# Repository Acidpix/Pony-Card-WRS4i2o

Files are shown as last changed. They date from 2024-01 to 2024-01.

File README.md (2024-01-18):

<p align="center" >
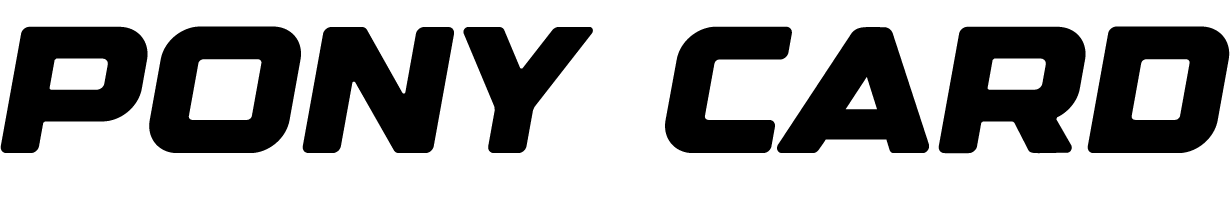
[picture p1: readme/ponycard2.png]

</p>
<p align="center">
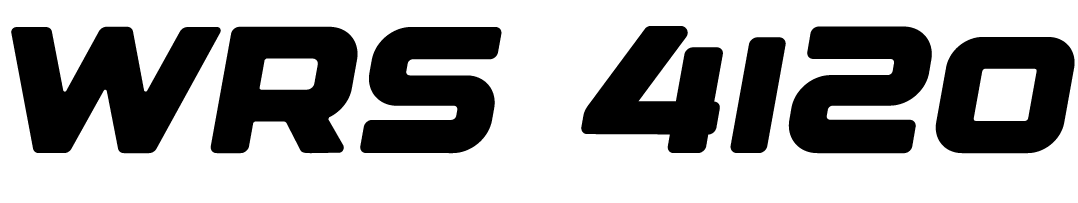
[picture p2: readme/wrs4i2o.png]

</p>

# Pony-Card-WRS4i2o

Pony-Card-WRS4i2o is a Wiegand/RS485 capable card for access controle powered by PoE

# Main feature 
  - Powered by PoE or 12V/2A input
  - Power sercurity device like badge reader in 12V/0.5A
  - Wiegand or RS485 input selectable by switch
  - In Wiegand mode, 1 digital output (e.g for drive 5V Led or buzzer from badge reader)   
  - 4 digital input (3V to 24V)
  - Drive 2 output NO/NC relay (230V/5A Max)
  - Can run on WiFi and/or Ethernet (e.g for failover)
  - Ready to Home assistant with EspHOME (Sample config avaliable)
  - Ready to MQTT with Tasmota (Base firmware avaliable)
  - -20C° +60C° running continous capability
  - Fit in DIN PLC Box like [this](https://fr.aliexpress.com/i/1005004933689728.html)
  - Dimention : 92.4mm X 87.5  

# Esp32 Pin Mapping 
  - GPIO 0 : Flash write mode Conected to CH340
  - GPIO 1 : UART_TX Conected to CH340
  - GPIO 2 : Free use in pin header
  - GPIO 3 : UART_RX Conected to CH340
  - GPIO 4 : Free use in pin header
  - GPIO 5 : Free use in pin header
  - GPIO 6 - 11 : Reserved by flash memory
  - GPIO 12 : Ethernet PHY Power
  - GPIO 13 : Wiegand D0 or RS485 RX
  - GPIO 14 : Wiegand D1 or RS485 TX
  - GPIO 15 : RS485 DIR or digital out in Wiegand mode (e.g for drive status LED on badge reader)
  - GPIO 16 : Free use in pin header
  - GPIO 17 : EMAC Clock out 180
  - GPIO 18 : MDIO(RMII)
  - GPIO 19 : EMAC TXD0(RMII)
  - GPIO 21 : EMAC TX Enable
  - GPIO 22 : EMAC TXD1(RMII)
  - GPIO 23 : MDC(RMII)
  - GPIO 25 : EMAC RXD0(RMII)
  - GPIO 26 : EMAC RXD1(RMII)
  - GPIO 27 : EMAC RX CRS DV
  - GPIO 32 : Relay 1
  - GPIO 33 : Relay 2
  - GPIO 34 : Digital Input 1 (3V - 24V)
  - GPIO 35 : Digital Input 2 (3V - 24V)
  - GPIO 36 : Digital Input 3 (3V - 24V)
  - GPIO 39 : Digital Input 4 (3V - 24V)

# Wiegand ESPHome example 

``` 
esphome:
  name: Pony Card WRS4i2o
  friendly_name: Pony_Card_WRS4i2o

esp32:
  board: esp32dev
  framework:
    type: arduino

# Enable logging
logger:

# Enable Home Assistant API
api:
  encryption:
    key: 

ota:
  password: 

ethernet:
  type: LAN8720
  mdc_pin: GPIO23
  mdio_pin: GPIO18
  clk_mode: GPIO17_OUT
  power_pin: GPIO12

globals:
  - id: autorized_badge
    type: int64_t
    restore_value: no
    initial_value: '5562314525698'

wiegand:
  - id: badgereader
    d0: GPIO13
    d1: GPIO14
    on_raw: 
      - if:
          condition:
            labda : 'return value == id(autorized_badge);
          then:
            - switch.toggle: r1
          else:
            - switch.toggle: r2
            - delay : 1s
            - switch.toggle: r2

binary_sensor:
  - platform: gpio
    pin: 
      number: 34
      inverted: true
    name: "input1"
  - platform: gpio
    pin: 
      number: 35
      inverted: true
    name: "input2"
  - platform: gpio
    pin: 
      number: 36
      inverted: true
    name: "input3"
  - platform: gpio
    pin: 
      number: 39
      inverted: true
    name: "input4"

output:
  - platform: gpio
    pin: 32
    id: 'Relay_1'  
  - platform: gpio
    pin: 33
    id: 'Relay_2'    

switch:
  - platform: output
    name: "Relay 1"
    id: "r1"
    output: 'Relay_1'
  - platform: output
    name: "Relay 2"
    id: "r2"
    output: 'Relay_2'
  - platform: gpio
    name: "LED"
    id: "led"
    pin:
      number: 15
      inverted: true 
``` 

# Misc
R49 was unpopulated resistance, because it's just for very old PoE device, support only type 1 PoE and this type need permanante 10mA current drain. But this produce 0.5w of heat and in certain condition make overhead the board, please populate only if your PoE injector dont work without an be careful of probaly over heating in +50C° environement.

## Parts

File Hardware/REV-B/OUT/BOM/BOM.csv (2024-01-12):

Item | Qty | Reference(s) | Value | LCSC/JLC Part Number | Mouser Part Number
1 | 3 | C1, C2, C7 | 22uF/6.3V/20%/X5R/C0603 | C2991805 | 81-GRM188R60J226ME0D
2 | 1 | C3 | 1nF/2000V/10%/X7R/C1206 | C725573 | 710-885342208024
3 | 9 | C4, C6, C9, C10, C11, C12, C13, C25, C27 | 100nF/16V/10%/X7R/C0402 | C1525 | 81-GRM155R71C104KA8J
4 | 1 | C5 | 56pF 25V | C107007
5 | 1 | C14 | 47uF 16V 1210 | C2918513
6 | 3 | C15, C34, C37 | 100nF/100V/10%/X7R/C0805 | C28233 | 810-C2012X7R2A104K
7 | 1 | C18 | 22uF 25V | C602037
8 | 1 | C26 | 2.2uF/6.3V/10%/X5R/C0603 | C412627 | 81-GCM188R70J225KE2D
9 | 1 | C31 | 1uF/10V/10%/X5R/C0603 | C3000819 | 77-VJ0603Y105KXQCWBC
10 | 1 | C35 | 15uF/100V/20% | C442918 | 661-EKYB101E150MF11D
11 | 1 | C38 | 12pF/50V/5%/COG/C0402 | C386126 | 963-UMK105CG120JVHF
12 | 1 | C39 | 470uF/16V/20%/Low_ESR/RM3.5/8.0x15mm | C428866 | NA
13 | 10 | D1, D3, D5, D7, D8, D9, D10, D11, D12, D16 | B5819W | C64885
14 | 1 | D2 | SMAJ58A/SMA | C151246 | 576-SMAJ58A
15 | 1 | D4 | SS510/100V/5A/0.85V/DO214AB(SMC) | C2985020 | 750-SS510C-HF
16 | 1 | D6 | STS232120B301 | C2985651 | 947-SM712.TCT
17 | 1 | D13 | SS34 | C408258
18 | 2 | D14, D15 | MB10S | C2892569
19 | 1 | FET1 | WPM2015-3/TR | C6562215 | 637-MMFTP3401
20 | 2 | IC2, IC3 | VOD207T | C146234 | 78-VOD207T
21 | 1 | IC4 | THVD1420DR | C3235215 | 595-THVD1420DR
22 | 1 | J2 | 1984963 | C7467028 | 651-1984963
23 | 1 | J3 | 0826-1X1T-GH-F |  | 530-0826-1X1T-GH-F
24 | 1 | J4 | USB_C_Receptacle_USB2.0 | C709357 | USB4105-GF-A
25 | 1 | J5 | 1985069 | C7470124 | 651-1985069
26 | 1 | J6 | 1985001 | C7467032 | 651-1985001
28 | 2 | K1, K2 | G5Q-1-DC12 | C59752 | 653-G5Q-1-DC12
29 | 1 | L1 | Sunlord MWSA1004S-330MT | C408490 | 994-DO3316P-333MLD
30 | 1 | L2 | FB0805/600R/2A | C81034 | 810-MPZ2012S601ATD25
31 | 1 | L3 | 10uH 3.5A 55mR | C168076
32 | 2 | LED1, LED2 | LED/BLUE/0603 | C2962098 | 710-150060VS75000
37 | 1 | PS1 | TPS54202DDCR | C191884 | 595-TPS54202DDCR
38 | 5 | Q1, Q2, Q3, Q4, Q5 | BC817-40(SOT23) | C146798 | 637-BC817-40
39 | 11 | R1, R5, R7, R21, R26, R27, R33, R34, R35, R36, R37 | 1k/R0603 | C73797 | 652-CR0603AFX1001ELF
40 | 4 | R2, R6, R14, R16 | 1.2kR/5%/1W/2512/CR2512-JW-122ELF | C2974106 | 652-CR2512-JW-122ELF
41 | 2 | R3, R17 | 2.2k/R0402 | C4202009 | 71-CRCW04022K20JNEDC
42 | 6 | R4, R19, R22, R23, R24, R30 | 10k/R0402 | C3020235 | 71-RCS040210K0FKED
43 | 4 | R8, R9, R10, R12 | 49.9R/1%/R0402 | C854345 | 667-ERJ-2RKF49R9X
44 | 2 | R11, R38 | 5.1k/R0402 | C105872
45 | 3 | R13, R15, R25 | 220R/R0402 | C284422 | 652-CR0402JW-221GLF
46 | 2 | R18, R32 | 470R/R0603 | C844564 | 71-CRCW0603470RFKEAC
47 | 1 | R20 | 12.1k/1%/R0603 | C2930059 | 652-CR0603FX-1212ELF
48 | 2 | R28, R31 | 10R/5%/pulse resistor/0603 | C319920 | 279-CPF0603F10RC1
49 | 1 | R29 | 130k/R0402 | C102797 | 652-CR0402FX-1303GLF
50 | 1 | R39 | 22.1kR 0402 | C163478
51 | 1 | R42 | 100kR 0402 | C60491
52 | 1 | R43 | 24.9k/1%/R0402 | C852664 | 652-CR0402FX-2492GLF
53 | 1 | R47 | 180k/1%/R0402 | C364850 | 652-CR0402FX-1803GLF
54 | 1 | R48 | 4.42k/1%/1/16W/R0402 | C103045 | 652-CR0402-FX4421GLF
55 | 1 | R49 | 4.7k/R2512 | C269368 | 652-CR2512-JW-472ELF
56 | 1 | R53 | 0.03R/1%/R1206 | C875624 | 71-WSL1206R0300FEA
57 | 1 | R55 | 4.7R/R0402 | C514781 | 652-CR0402-J/-4R7GLF
58 | 1 | R59 | 21k/1%/R0402 | C2692912 | 652-CR0402-FX2102GLF
59 | 1 | R60 | 300k/1%/R0402 | C364989 | 652-CR0402-JW-304GLF
60 | 1 | Reset1 | T1107A(6x3,8x2,5MM) | C97440
61 | 2 | RN1, RN2 | 2.2k/5%/0603x4 | C102658 | 652-CAT16A-222J4LF
62 | 1 | T1 | LMUN2211LT1G(SOT-23) | C12775
63 | 1 | TVS2 | ESDS314DBVR(SOT-23-6) | C1847859 | 595-ESDS314DBVR
64 | 1 | U1 | LAN8710A-EZC(QFN32) | C46185 | 886-LAN8710A-EZC-TR
65 | 1 | U2 | CH340C | C84681
66 | 1 | U3 | ESP-WROOM-32 | C701341 | 356-ESP32WRM32E132PH
67 | 1 | U6 | TPS2376DDAR-H (SO-8) | C544899 | 595-TPS2376D
68 | 1 | U7 | TX4138(ESOIC-8) | C329267

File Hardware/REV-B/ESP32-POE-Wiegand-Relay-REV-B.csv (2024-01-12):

Source: | C:\Users\Pixi\OneDrive\Documents\CAO\Pony-Card-WRS4i2o\Hardware\REV-B\ESP32-POE-Wiegand-Relay-REV-B.kicad_sch
Date: | 1/12/2024 1:11:56 PM
Tool: | Eeschema 7.0.8
Generator: | C:\Program Files\KiCad\7.0\bin\scripting\plugins/bom_csv_grouped_by_value.py
Component Count: | 125
Collated Components:
Item | Qty | Reference(s) | Value | LibPart | Footprint | Datasheet | DNP | Height | LCSC/JLC Part Number | Manufacturer_Name | Manufacturer_Part_Number | Mouser Part Number | Mouser Price/Stock
1 | 3 | C1, C2, C7 | 22uF/6.3V/20%/X5R/C0603 | Device:C | Capacitor_SMD:C_0603_1608Metric | ~ |  |  | C2991805 |  |  | 81-GRM188R60J226ME0D
2 | 1 | C3 | 1nF/2000V/10%/X7R/C1206 | Device:C | Capacitor_SMD:C_1206_3216Metric | ~ |  |  | C725573 |  |  | 710-885342208024
3 | 9 | C4, C6, C9, C10, C11, C12, C13, C25, C27 | 100nF/16V/10%/X7R/C0402 | Device:C | Capacitor_SMD:C_0402_1005Metric | ~ |  |  | C1525 |  |  | 81-GRM155R71C104KA8J
4 | 1 | C5 | 56pF 25V | Device:C_Small | Capacitor_SMD:C_0402_1005Metric | ~ |  |  | C107007
5 | 1 | C14 | 47uF 16V 1210 | Device:C_Small | Capacitor_SMD:C_1210_3225Metric | ~ |  |  | C2918513
6 | 3 | C15, C34, C37 | 100nF/100V/10%/X7R/C0805 | Device:C | Capacitor_SMD:C_0805_2012Metric | ~ |  |  | C28233 |  |  | 810-C2012X7R2A104K
7 | 1 | C18 | 22uF 25V | Device:C_Small | Capacitor_SMD:C_0805_2012Metric | ~ |  |  | C602037
8 | 1 | C26 | 2.2uF/6.3V/10%/X5R/C0603 | Device:C | Capacitor_SMD:C_0603_1608Metric | ~ |  |  | C412627 |  |  | 81-GCM188R70J225KE2D
9 | 1 | C31 | 1uF/10V/10%/X5R/C0603 | Device:C | Capacitor_SMD:C_0603_1608Metric | ~ |  |  | C3000819 |  |  | 77-VJ0603Y105KXQCWBC
10 | 1 | C35 | 15uF/100V/20% | Device:C_Polarized | Capacitor_THT:CP_Radial_D5.0mm_P2.00mm | ~ |  |  | C442918 |  |  | 661-EKYB101E150MF11D
11 | 1 | C38 | 12pF/50V/5%/COG/C0402 | Device:C | Capacitor_SMD:C_0402_1005Metric | ~ |  |  | C386126 |  |  | 963-UMK105CG120JVHF
12 | 1 | C39 | 470uF/16V/20%/Low_ESR/RM3.5/8.0x15mm | Device:C_Polarized | Capacitor_THT:CP_Radial_D8.0mm_P3.50mm | ~ |  |  | C428866 |  |  | NA
13 | 10 | D1, D3, D5, D7, D8, D9, D10, D11, D12, D16 | B5819W | Diode:1N5817 | Diode_SMD:D_SOD-123 | https://www.vishay.com/docs/85748/1n4148w.pdf |  |  | C64885
14 | 1 | D2 | SMAJ58A/SMA | Diode:SMAJ58A | Diode_SMD:D_SMA | https://www.littelfuse.com/media?itemid=75e32973-b177-4ee3-a0ff-cedaf1abdb93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 |  |  | C151246 |  |  | 576-SMAJ58A
15 | 1 | D4 | SS510/100V/5A/0.85V/DO214AB(SMC) | Device:D_Schottky_Small | Diode_SMD:D_SMC | ~ |  |  | C2985020 |  |  | 750-SS510C-HF
16 | 1 | D6 | STS232120B301 | Power_Protection:SP0502BAHT | Package_TO_SOT_SMD:SOT-23 | https://www.mouser.fr/datasheet/2/87/eaton_sts232xxxbxxx_tvs_diode_array_esd_suppressor-1903475.pdf |  |  | C2985651 |  |  | 947-SM712.TCT
17 | 1 | D13 | SS34 | Diode:1N5817 | Diode_SMD:D_SMA | https://www.vishay.com/docs/85748/1n4148w.pdf |  |  | C408258
18 | 2 | D14, D15 | MB10S | SamacSys_Parts:MDB10S YONG | SamacSys_Parts:SOP-4_3.8x4.1mm_P2.54mm_MB10S-YONG | https://datasheet.lcsc.com/lcsc/2109292030_YONGYUTAI-MB10S_C2892569.pdf |  |  | C2892569
19 | 1 | FET1 | WPM2015-3/TR | SamacSys_Parts:P-MOS+DIOD | Package_TO_SOT_SMD:SOT-23-3 |  |  |  | C6562215 |  |  | 637-MMFTP3401
20 | 2 | IC2, IC3 | VOD207T | SamacSys_Parts:VOD207T | SamacSys_Parts:SOIC127P610X323-8N | http://www.vishay.com/docs/81956/vod205t.pdf |  | 3.23 | C146234 | Vishay | VOD207T | 78-VOD207T | https://www.mouser.co.uk/ProductDetail/Vishay-Semiconductors/VOD207T?qs=fbkhFuCHoTaX1ClwC%252BJsLA%3D%3D
21 | 1 | IC4 | THVD1420DR | SamacSys_Parts:THVD1420DR | SamacSys_Parts:SOIC127P600X175-8N | https://www.ti.com/lit/ds/symlink/thvd1420.pdf?ts=1627460855173 |  | 1.75 | C3235215 | Texas Instruments | THVD1420DR | 595-THVD1420DR | https://www.mouser.co.uk/ProductDetail/Texas-Instruments/THVD1420DR?qs=iLbezkQI%252Bsio9fbTvISdEg%3D%3D
22 | 1 | J2 | 1984963 | SamacSys_Parts:1984963 | SamacSys_Parts:1984963 | https://media.digikey.com/pdf/Data%20Sheets/Phoenix%20Contact%20PDFs/COMBICON%20Spring-Cage%20PCB%20Term.%20Blocks.pdf |  | 13.1 | C7467028 | Phoenix Contact | 1984963 | 651-1984963 | https://www.mouser.co.uk/ProductDetail/Phoenix-Contact/1984963?qs=W3wJikR1%252BS77jmVAo79BfA%3D%3D
23 | 1 | J3 | 0826-1X1T-GH-F | SamacSys_Parts:0826-1X1T-GH-F | SamacSys_Parts:08261X1TGHF | https://datasheet.datasheetarchive.com/originals/distributors/Datasheets-DGA2/203609.pdf |  |  |  | Bel Magnetic Solutions | 0826-1X1T-GH-F | 530-0826-1X1T-GH-F | https://www.mouser.co.uk/ProductDetail/Bel-Magnetic-Solutions/0826-1X1T-GH-F?qs=SRYZG9HaIQ0Mc3bZi1IotQ%3D%3D
24 | 1 | J4 | USB_C_Receptacle_USB2.0 | Connector:USB_C_Receptacle_USB2.0 | Connector_USB:USB_C_Receptacle_G-Switch_GT-USB-7010ASV | https://www.usb.org/sites/default/files/documents/usb_type-c.zip |  |  | C709357 |  |  | USB4105-GF-A
25 | 1 | J5 | 1985069 | SamacSys_Parts:1985069 | SamacSys_Parts:1985069 | https://datasheet.datasheetarchive.com/originals/dk/DKDS-5/85375.pdf |  | 13.1 | C7470124 | Phoenix Contact | 1985069 | 651-1985069 | https://www.mouser.co.uk/ProductDetail/Phoenix-Contact/1985069?qs=gjk32EaArKK7mdP%252BL%2F2B4Q%3D%3D
26 | 1 | J6 | 1985001 | SamacSys_Parts:1985001 | SamacSys_Parts:1985001 | https://datasheet.datasheetarchive.com/originals/distributors/SFDatasheet-2/sf-00059053.pdf |  | 13.1 | C7467032 | Phoenix Contact | 1985001 | 651-1985001 | https://www.mouser.co.uk/ProductDetail/Phoenix-Contact/1985001?qs=zNxsRDw9Fqyp1BhRo7hyKA%3D%3D
27 | 1 | J8 | Conn_01x10 | Connector_Generic:Conn_01x10 | Connector_PinHeader_2.54mm:PinHeader_1x10_P2.54mm_Vertical | ~
28 | 2 | K1, K2 | G5Q-1-DC12 | SamacSys_Parts:G5Q-1-DC12 | SamacSys_Parts:G5Q1DC12 | https://componentsearchengine.com/Datasheets/1/G5Q-1-DC12.pdf |  | 16.2 | C59752 | Omron Electronics | G5Q-1-DC12 | 653-G5Q-1-DC12 | https://www.mouser.co.uk/ProductDetail/Omron-Electronics/G5Q-1-DC12?qs=nNiD76Ca0%252Bu28Ix61rgPyA%3D%3D
29 | 1 | L1 | Sunlord MWSA1004S-330MT | SamacSys_Parts:DO3316P-333MLD | Inductor_SMD:L_Sunlord_MWSA1004S | https://www.coilcraft.com/pdfs/do3316p.pdf |  | 5.21 | C408490 | COILCRAFT | DO3316P-333MLD | 994-DO3316P-333MLD | https://www.mouser.co.uk/ProductDetail/Coilcraft/DO3316P-333MLD?qs=zCSbvcPd3paYSfmHDR4Exw%3D%3D
30 | 1 | L2 | FB0805/600R/2A | Device:L | Resistor_SMD:R_0805_2012Metric | ~ |  |  | C81034 |  |  | 810-MPZ2012S601ATD25
31 | 1 | L3 | 10uH 3.5A 55mR | Device:L | Inductor_SMD:L_Changjiang_FNR6045S | ~ |  |  | C168076
32 | 2 | LED1, LED2 | LED/BLUE/0603 | Device:LED | LED_SMD:LED_0603_1608Metric | ~ |  |  | C2962098 |  |  | 710-150060VS75000
33 | 1 | MH1 | Mounting_hole_Shield_3.3mm | :Mounting_hole_Shield_3.3mm_2 | MountingHole:MountingHole_3.2mm_M3_Pad |  |  |  | NA |  |  | NA
34 | 1 | MH2 | Mounting_hole_Shield_3.3mm | :Mounting_hole_Shield_3.3mm_3 | MountingHole:MountingHole_3.2mm_M3_Pad |  |  |  | NA |  |  | NA
35 | 1 | MH3 | Mounting_hole_Shield_3.3mm | import-Library:Mounting_hole_Shield_3.3mm | MountingHole:MountingHole_3.2mm_M3_Pad |  |  |  | NA |  |  | NA
36 | 1 | MH4 | Mounting_hole_Shield_3.3mm | :Mounting_hole_Shield_3.3mm_1 | MountingHole:MountingHole_3.2mm_M3_Pad |  |  |  | NA |  |  | NA
37 | 1 | PS1 | TPS54202DDCR | SamacSys_Parts:TPS54202DDCR | SOT95P280X110-6N | http://www.ti.com/lit/gpn/tps54202 |  | 1.1 | C191884 | Texas Instruments | TPS54202DDCR | 595-TPS54202DDCR | https://www.mouser.co.uk/ProductDetail/Texas-Instruments/TPS54202DDCR?qs=uP22XH7NdCsJtN%2Fq54jCtQ%3D%3D
38 | 5 | Q1, Q2, Q3, Q4, Q5 | BC817-40(SOT23) | Device:Q_NPN_BEC | Package_TO_SOT_SMD:SOT-23 | ~ |  |  | C146798 |  |  | 637-BC817-40
39 | 11 | R1, R5, R7, R21, R26, R27, R33, R34, R35, R36, R37 | 1k/R0603 | Device:R | Resistor_SMD:R_0603_1608Metric | ~ |  |  | C73797 |  |  | 652-CR0603AFX1001ELF
40 | 4 | R2, R6, R14, R16 | 1.2kR/5%/1W/2512/CR2512-JW-122ELF | Device:R | Resistor_SMD:R_2512_6332Metric | ~ |  |  | C2974106 |  |  | 652-CR2512-JW-122ELF
41 | 2 | R3, R17 | 2.2k/R0402 | Device:R | Resistor_SMD:R_0402_1005Metric | ~ |  |  | C4202009 |  |  | 71-CRCW04022K20JNEDC
42 | 6 | R4, R19, R22, R23, R24, R30 | 10k/R0402 | Device:R | Resistor_SMD:R_0402_1005Metric | ~ |  |  | C3020235 |  |  | 71-RCS040210K0FKED
43 | 4 | R8, R9, R10, R12 | 49.9R/1%/R0402 | Device:R | Resistor_SMD:R_0402_1005Metric | ~ |  |  | C854345 |  |  | 667-ERJ-2RKF49R9X
44 | 2 | R11, R38 | 5.1k/R0402 | Device:R | Resistor_SMD:R_0402_1005Metric | ~ |  |  | C105872
45 | 3 | R13, R15, R25 | 220R/R0402 | Device:R | Resistor_SMD:R_0402_1005Metric | ~ |  |  | C284422 |  |  | 652-CR0402JW-221GLF
46 | 2 | R18, R32 | 470R/R0603 | Device:R | Resistor_SMD:R_0603_1608Metric | ~ |  |  | C844564 |  |  | 71-CRCW0603470RFKEAC
47 | 1 | R20 | 12.1k/1%/R0603 | Device:R | Resistor_SMD:R_0603_1608Metric | ~ |  |  | C2930059 |  |  | 652-CR0603FX-1212ELF
48 | 2 | R28, R31 | 10R/5%/pulse resistor/0603 | Device:R | Resistor_SMD:R_0603_1608Metric | ~ |  |  | C319920 |  |  | 279-CPF0603F10RC1
49 | 1 | R29 | 130k/R0402 | Device:R | Resistor_SMD:R_0402_1005Metric | ~ |  |  | C102797 |  |  | 652-CR0402FX-1303GLF
50 | 1 | R39 | 22.1kR 0402 | Device:R_Small | Resistor_SMD:R_0402_1005Metric | ~ |  |  | C163478
51 | 1 | R42 | 100kR 0402 | Device:R_Small | Resistor_SMD:R_0402_1005Metric | ~ |  |  | C60491
52 | 1 | R43 | 24.9k/1%/R0402 | Device:R | Resistor_SMD:R_0402_1005Metric | ~ |  |  | C852664 |  |  | 652-CR0402FX-2492GLF
53 | 1 | R47 | 180k/1%/R0402 | Device:R | Resistor_SMD:R_0402_1005Metric | ~ |  |  | C364850 |  |  | 652-CR0402FX-1803GLF
54 | 1 | R48 | 4.42k/1%/1/16W/R0402 | Device:R | Resistor_SMD:R_0402_1005Metric | ~ |  |  | C103045 |  |  | 652-CR0402-FX4421GLF
55 | 1 | R49 | 4.7k/R2512 | Device:R | Resistor_SMD:R_2512_6332Metric | ~ |  |  | C269368 |  |  | 652-CR2512-JW-472ELF
56 | 1 | R53 | 0.03R/1%/R1206 | Device:R | Resistor_SMD:R_1206_3216Metric | ~ |  |  | C875624 |  |  | 71-WSL1206R0300FEA
57 | 1 | R55 | 4.7R/R0402 | Device:R | Resistor_SMD:R_0402_1005Metric | ~ |  |  | C514781 |  |  | 652-CR0402-J/-4R7GLF
58 | 1 | R59 | 21k/1%/R0402 | Device:R | Resistor_SMD:R_0402_1005Metric | ~ |  |  | C2692912 |  |  | 652-CR0402-FX2102GLF
59 | 1 | R60 | 300k/1%/R0402 | Device:R | Resistor_SMD:R_0402_1005Metric | ~ |  |  | C364989 |  |  | 652-CR0402-JW-304GLF
60 | 1 | Reset1 | T1107A(6x3,8x2,5MM) | import-Library:SIDE_WTCM-TR(3x4) | Button_Switch_THT:SW_PUSH_6mm |  |  |  | C97440
61 | 2 | RN1, RN2 | 2.2k/5%/0603x4 | SamacSys_Parts:CAY16-222J4LF | Resistor_SMD:R_Array_Concave_4x0603 | http://www.bourns.com/docs/Product-Datasheets/CATCAY.pdf |  |  | C102658 | Bourns | CAY16-222J4LF | 652-CAT16A-222J4LF | https://www.mouser.co.uk/ProductDetail/Bourns/CAY16-222J4LF?qs=36H9kbV3T2y0WLGod7%2FgTA%3D%3D
62 | 1 | T1 | LMUN2211LT1G(SOT-23) | SamacSys_Parts:LMUN2211LT1G(SOT-23) | Package_TO_SOT_SMD:SOT-23 |  |  |  | C12775
63 | 1 | TVS2 | ESDS314DBVR(SOT-23-6) | SamacSys_Parts:ESDS314DBVR(SOT-23-5) | Package_TO_SOT_SMD:SOT-23-6 | https://www.ti.com/lit/gpn/esds314 |  |  | C1847859 |  |  | 595-ESDS314DBVR
64 | 1 | U1 | LAN8710A-EZC(QFN32) | SamacSys_Parts:LAN8710A-EZC(QFN32) | SamacSys_Parts:QFN50P500X500X100-33N-D |  |  |  | C46185 |  |  | 886-LAN8710A-EZC-TR
65 | 1 | U2 | CH340C | Interface_USB:CH340C | Package_SO:SOIC-16_3.9x9.9mm_P1.27mm | https://datasheet.lcsc.com/szlcsc/Jiangsu-Qin-Heng-CH340C_C84681.pdf |  |  | C84681
66 | 1 | U3 | ESP-WROOM-32 | SamacSys_Parts:ESP-WROOM-32 | SamacSys_Parts:ESP32WROOM32EN4 |  |  |  | C701341 |  |  | 356-ESP32WRM32E132PH
67 | 1 | U6 | TPS2376DDAR-H (SO-8) | SamacSys_Parts:TPS2375PW(TSSOP-8) | SamacSys_Parts:SOIC127P600X175-8N | https://www.ti.com/lit/gpn/tps2375 |  |  | C544899 |  |  | 595-TPS2376D
68 | 1 | U7 | TX4138(ESOIC-8) | SamacSys_Parts:TX4138(ESOIC-8) | SamacSys_Parts:SOIC8E | https://datasheet.lcsc.com/lcsc/1811141153_XDS-TX4138_C329267.pdf |  |  | C329267

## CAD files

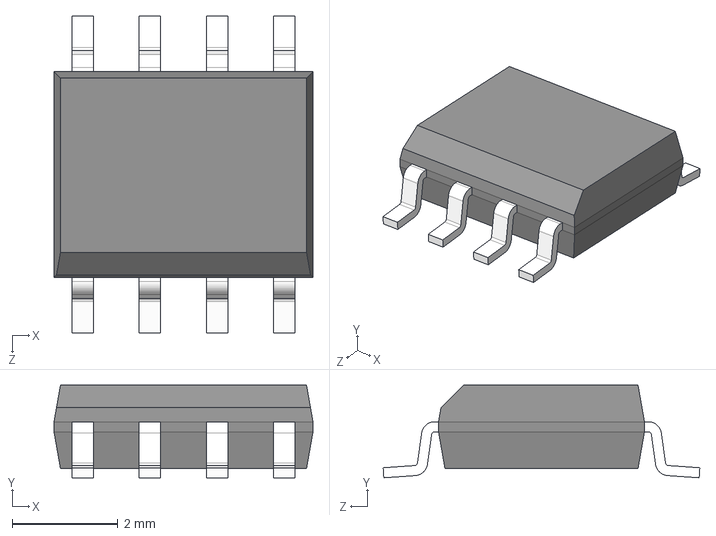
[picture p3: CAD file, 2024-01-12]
Hardware/REV-B/3d/SO-8_150mil---SN65HVDA1050AQDRQ1.STEP
4.90 x 1.75 x 5.99 mm

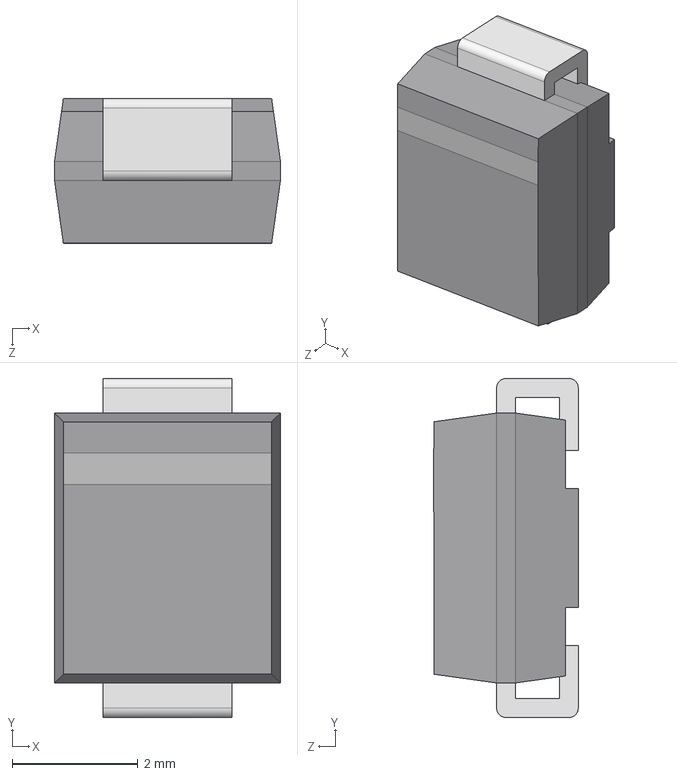
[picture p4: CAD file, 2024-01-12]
Hardware/REV-B/3d/DO-214AA_SMB.step
3.60 x 5.40 x 2.30 mm

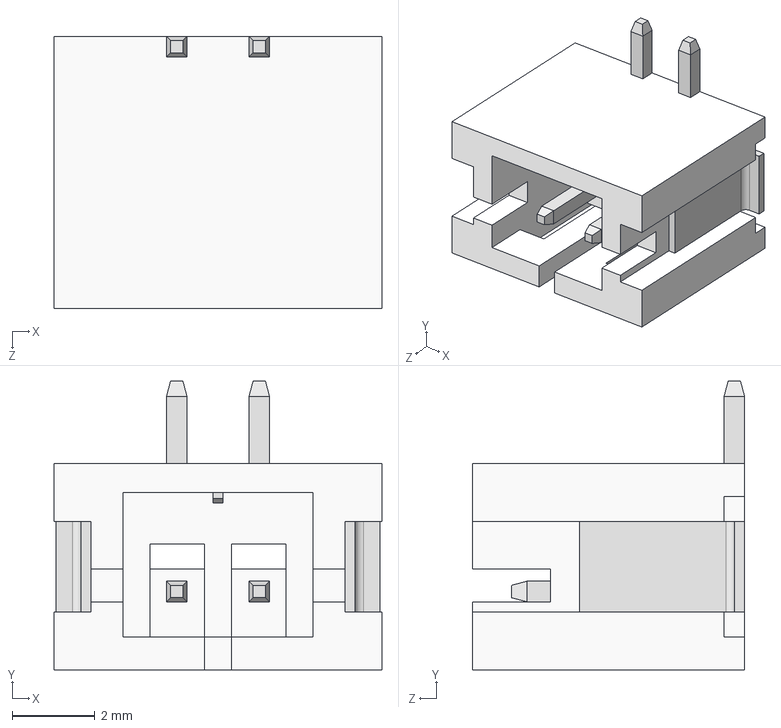
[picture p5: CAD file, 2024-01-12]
Hardware/REV-B/3d/JST_B2B-PH-SM4-TB(DW02R).step
7.95 x 7.00 x 6.60 mm

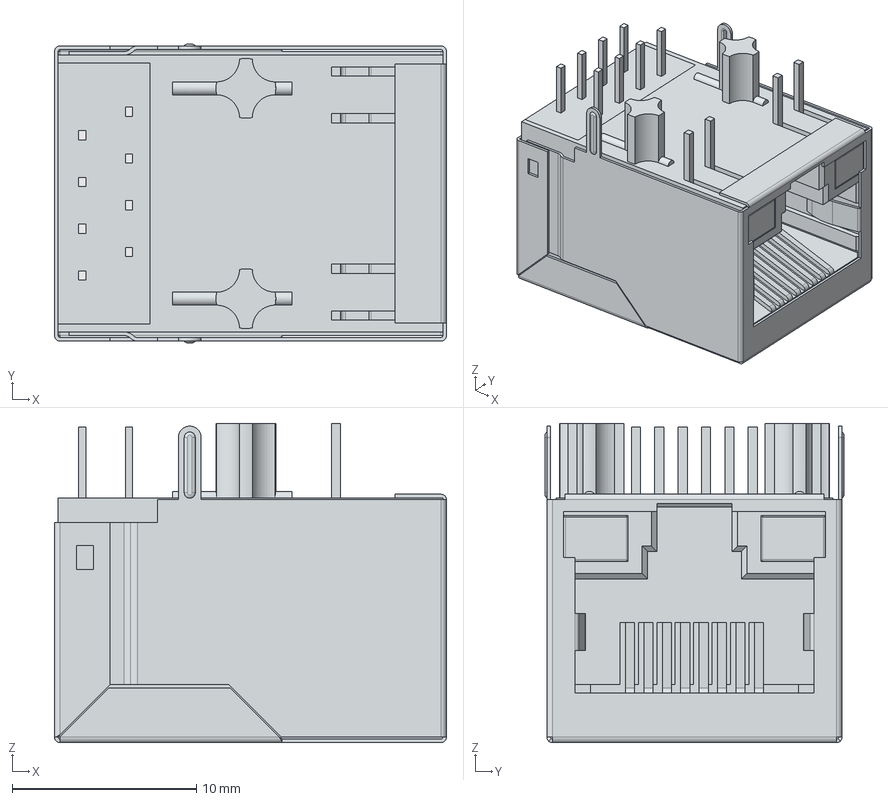
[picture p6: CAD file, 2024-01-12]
Hardware/REV-B/3d/Connector_1Port_RJ45_Magjack_10-100Base-T_AutoMDIX_Wurth_Electronics-7499010441.stp
21.3 x 16.2 x 17.4 mm
Shielding
Insulator 3
Insulator 1
Insulator 2
Green_Yellow_LED x 2

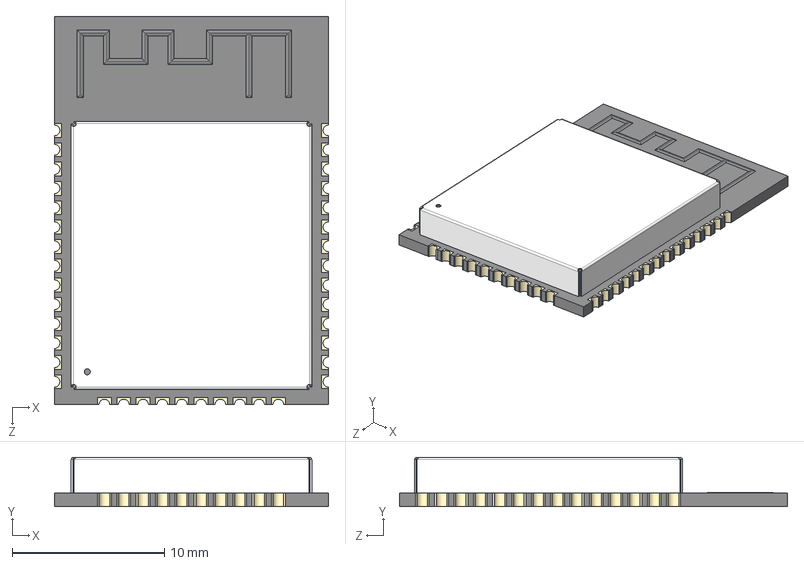
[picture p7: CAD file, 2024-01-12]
Hardware/REV-B/3d/ESP32-WROOM-32D-56544.STEP
18.0 x 3.25 x 25.5 mm

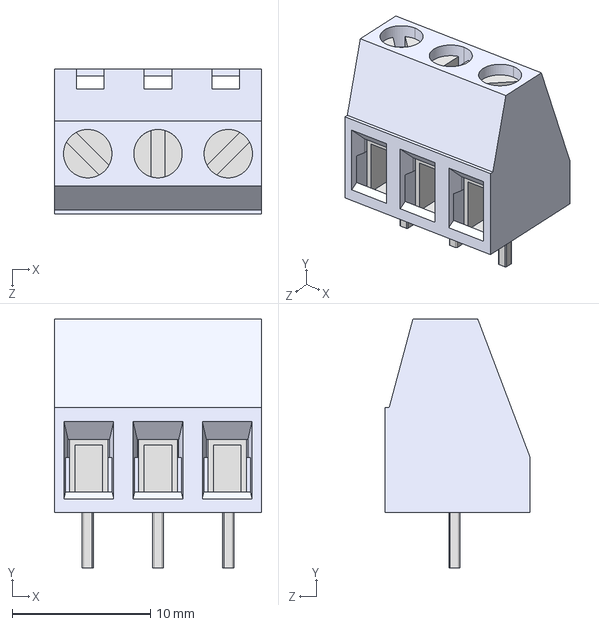
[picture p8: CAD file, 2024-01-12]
Hardware/REV-B/3d/klema-5mm-3pin.step
15.0 x 18.0 x 10.5 mm

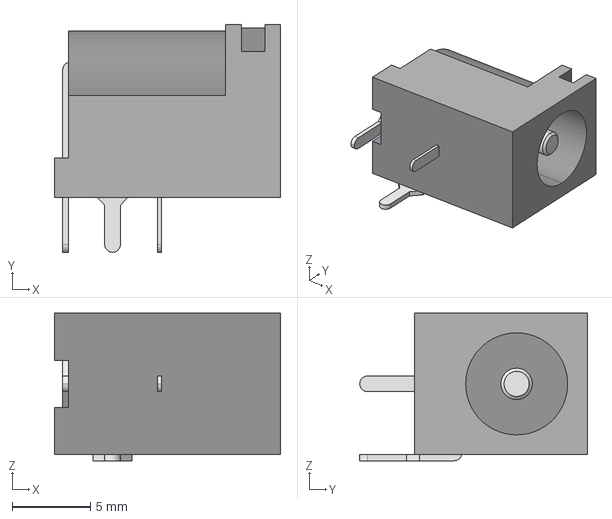
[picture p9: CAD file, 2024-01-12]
Hardware/REV-B/3d/pj-102ah.stp
14.4 x 14.5 x 9.40 mm

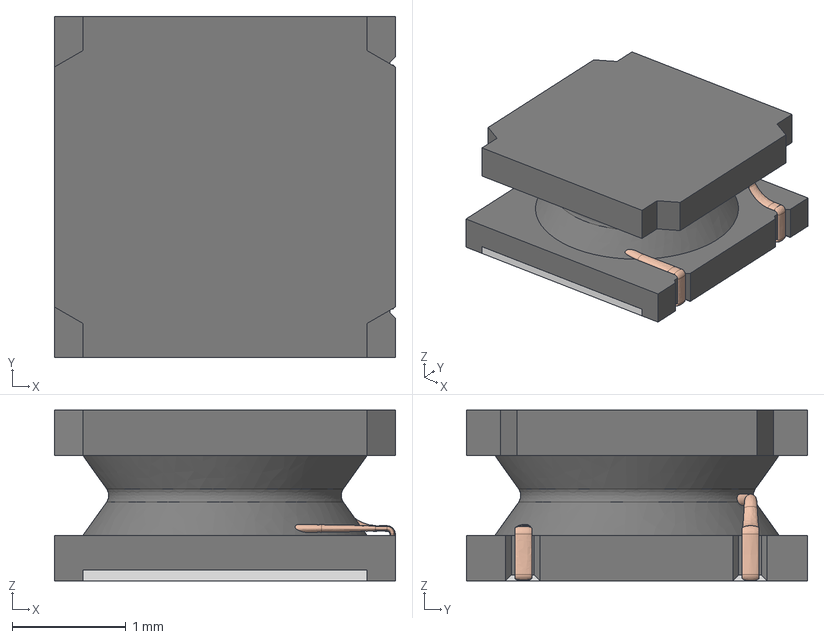
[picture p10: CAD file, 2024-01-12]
Hardware/REV-B/3d/L-CD32_shielded.step
3.00 x 3.00 x 1.50 mm

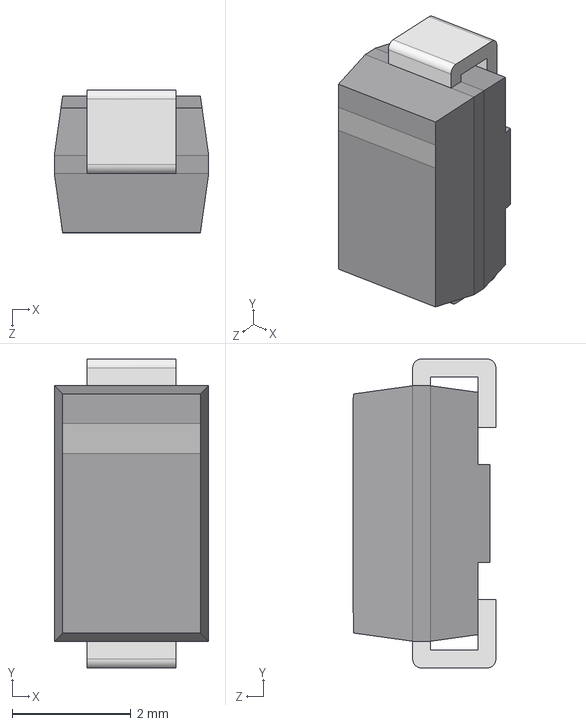
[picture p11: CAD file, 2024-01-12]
Hardware/REV-B/3d/DO-214AC_SMA.step
2.60 x 5.20 x 2.40 mm

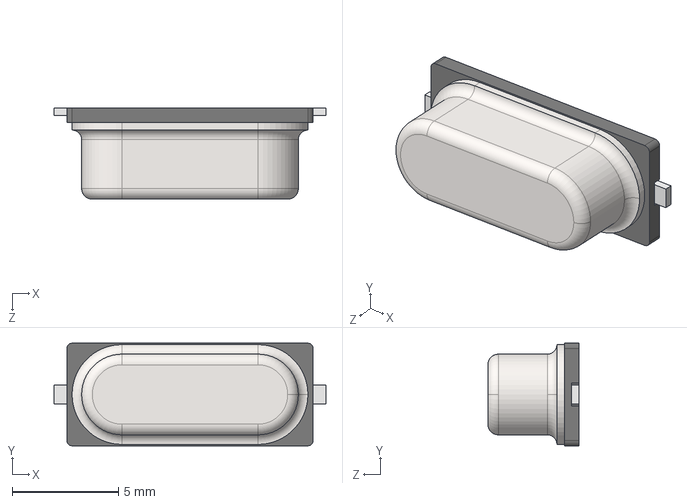
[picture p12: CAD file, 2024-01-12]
Hardware/REV-B/3d/User_Library-Crystal_HC49_US-SM.step
12.8 x 4.83 x 4.30 mm

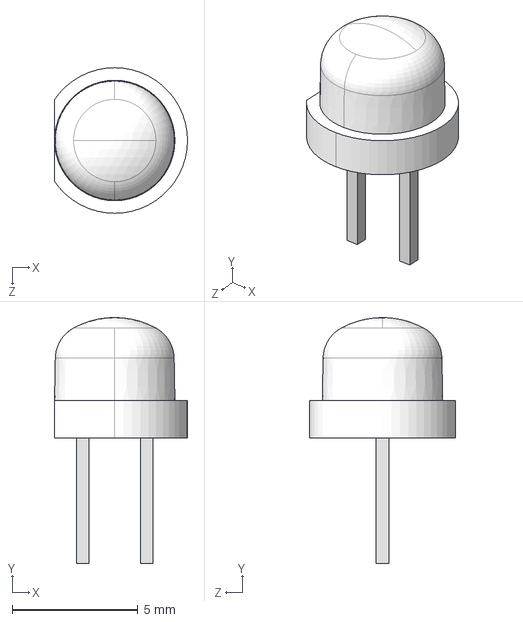
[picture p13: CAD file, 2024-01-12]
Hardware/REV-B/3d/LED5mm_120.STEP
5.30 x 9.80 x 5.80 mm

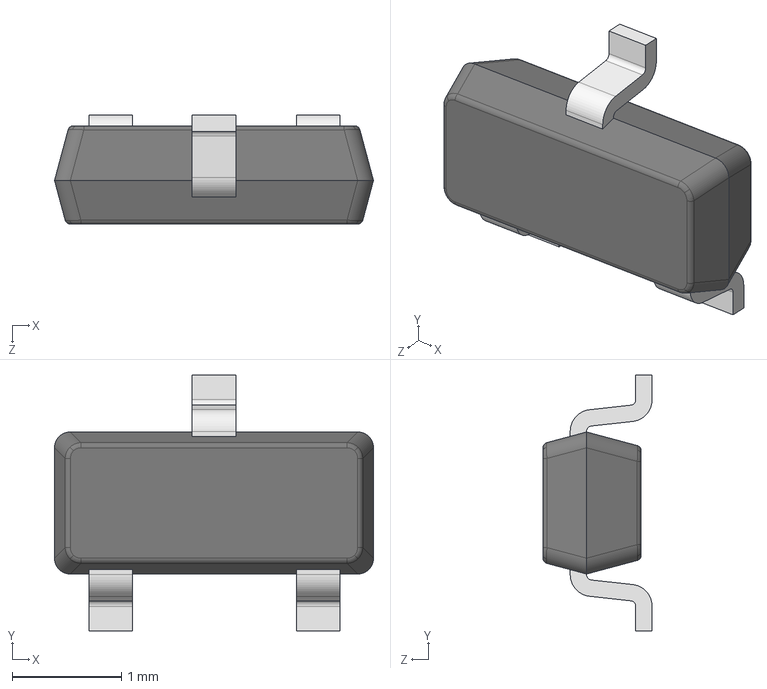
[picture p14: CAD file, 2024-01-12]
Hardware/REV-B/3d/BAT54.step
2.92 x 2.34 x 1.00 mm

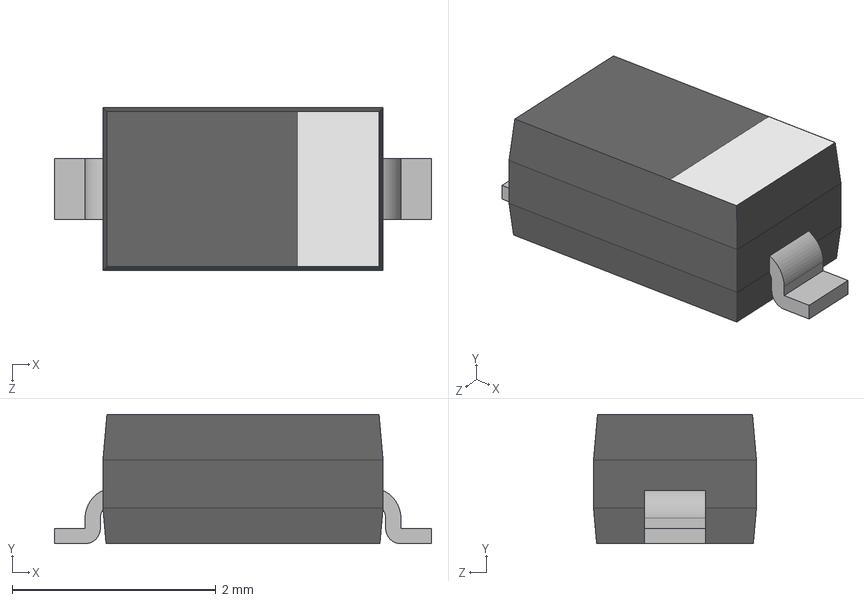
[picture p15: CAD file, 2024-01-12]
Hardware/REV-B/3d/SOD123.step
3.70 x 1.27 x 1.60 mm

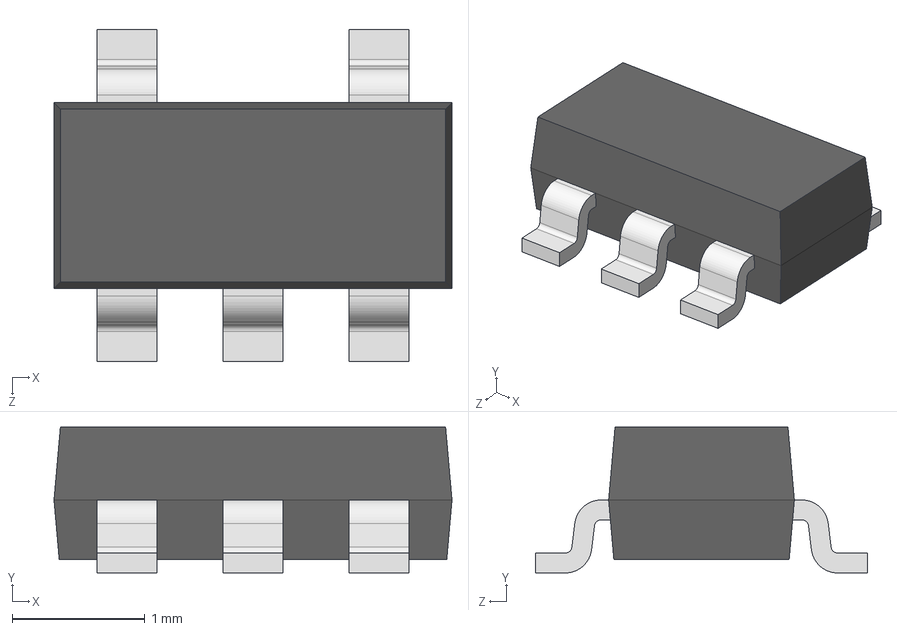
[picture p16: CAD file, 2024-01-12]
Hardware/REV-B/3d/SOT-23-5.step
3.00 x 1.10 x 2.50 mm

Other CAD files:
Hardware/REV-B/3d/QSG5032.step
Hardware/REV-B/3d/TEConnectivity -ORWH-SH-124D1F000.stp
Hardware/REV-B/3d/QFN32_5x5.step
Hardware/REV-B/3d/BH-10__64.step
Hardware/REV-A/3d/434121043836 (rev1).stp
Hardware/REV-A/3d/5040771891.stp
Hardware/REV-A/3d/BH-10__64.step
Hardware/REV-A/3d/QFN32_5x5.step
Hardware/REV-A/3d/QSG5032.step
Hardware/REV-A/3d/SOT-23.step
Hardware/REV-A/3d/TEConnectivity -ORWH-SH-124D1F000.stp
Hardware/REV-A/3d/User Library-GP1UE26.STEP
Hardware/REV-A/3d/esp-wroom-32.step
Hardware/REV-A/3d/usb_micro_4p.stp
Hardware/REV-B/3d/434121043836 (rev1).stp
Hardware/REV-B/3d/5040771891.stp
Hardware/REV-B/3d/SOT-23.step
Hardware/REV-B/3d/User Library-GP1UE26.STEP
Hardware/REV-B/3d/esp-wroom-32.step
Hardware/REV-B/3d/usb_micro_4p.stp

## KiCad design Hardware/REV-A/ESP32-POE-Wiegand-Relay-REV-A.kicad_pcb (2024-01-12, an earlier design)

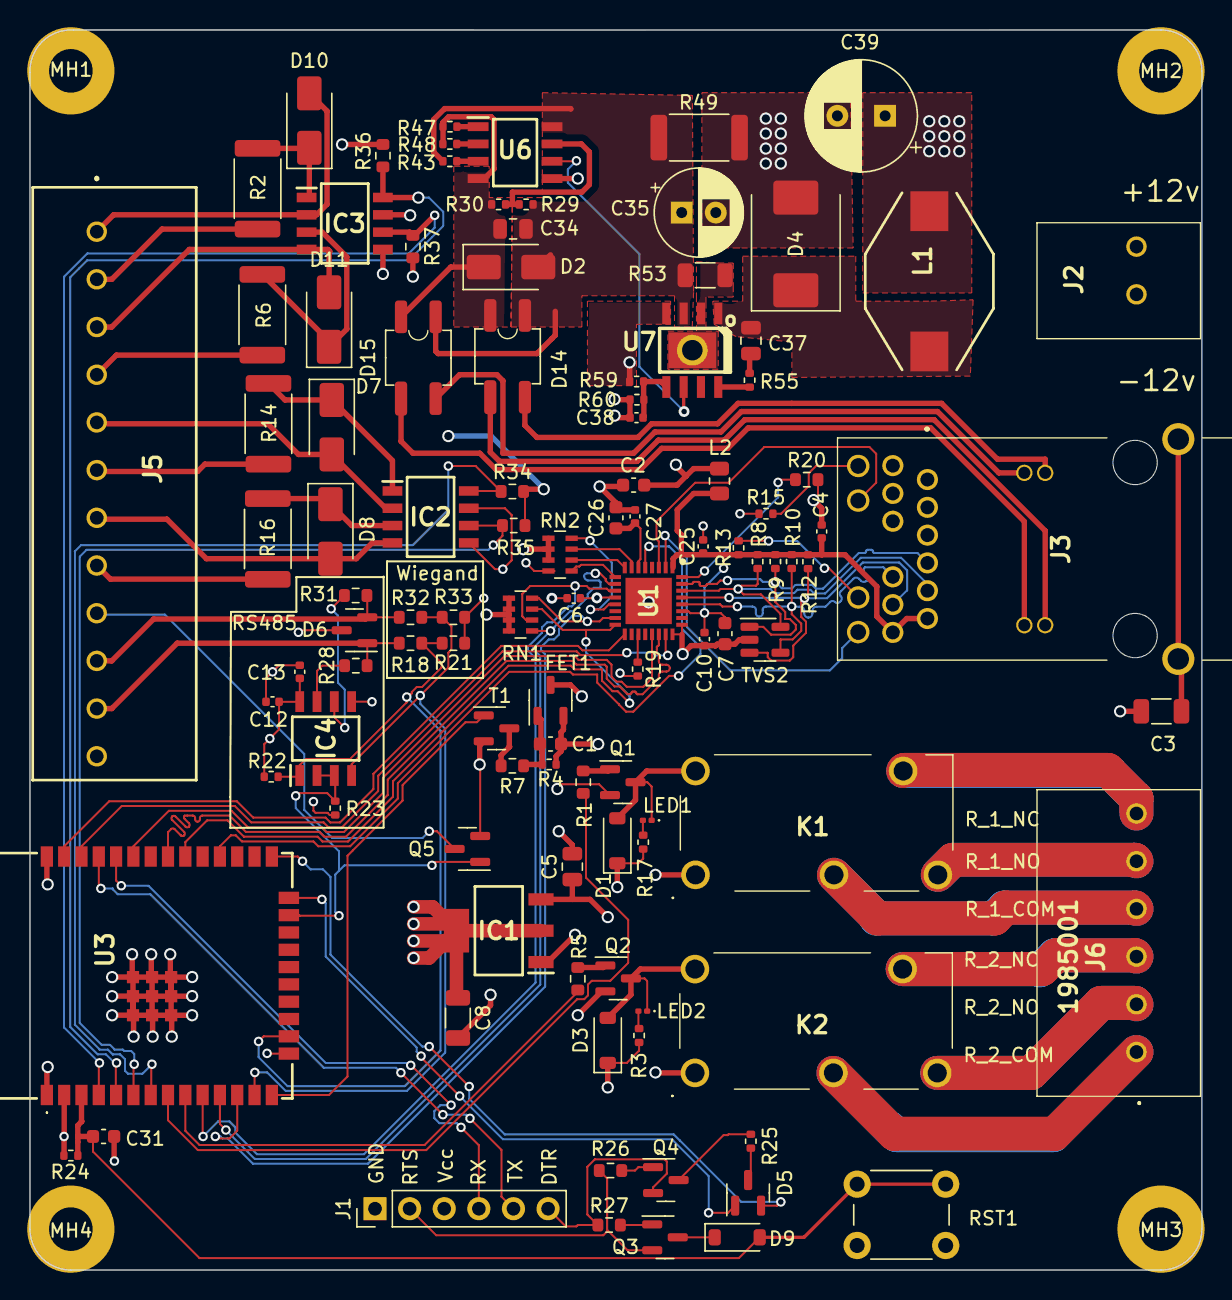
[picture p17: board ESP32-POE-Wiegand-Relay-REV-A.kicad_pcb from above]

Board: 4 copper layers, 86.0 x 91.0 mm, 111 parts (0 on the bottom side), 99 nets.

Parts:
C1, C2, C7: 22uF/6.3V/20%/X5R/C0603; C_0603_1608Metric
C3: 1nF/2000V/10%/X7R/C1206; C_1206_3216Metric
C4, C6, C10, C12, C13, C25, C27: 100nF/16V/10%/X7R/C0402; C_0402_1005Metric
C5: 10uF/16v/10%/0805; C_0805_2012Metric
C8: 22uF/6.3v/10%/1206; C_1206_3216Metric
C26: 2.2uF/6.3V/10%/X5R/C0603; C_0603_1608Metric
C31: 1uF/10V/10%/X5R/C0603; C_0603_1608Metric
C34, C37: 100nF/100V/10%/X7R/C0805; C_0805_2012Metric
C35: 15uF/100V/20%/RM2.5/6.3x11mm(Farnell:1281844); CP_Radial_D6.3mm_P2.50mm
C38: 12pF/50V/5%/COG/C0402; C_0402_1005Metric
C39: 470uF/16V/20%/Low_ESR/RM3.5/8.0x15mm; CP_Radial_D8.0mm_P3.50mm
D1, D3, D9: 1N5819S4(SOD-123); D_SOD-123
D2: SMAJ58A/SMA; D_SMA
D4: SS510/100V/5A/0.85V/DO214AB(SMC); D_SMC
D5: BAT54C(SOT23-3); SOT-23
D6: STS232120B301; SOT-23
D7, D8, D10, D11: Diode 1KV; D_SMA
D14, D15: MDB10S YONG; SOP-4_3.8x4.1mm_P2.54mm_MB10S-YONG
FET1: WPM2015-3/TR; SOT-23-3
IC1: AZ1117CH-3.3TRG1; SOT230P700X180-4N
IC2, IC3: VOD207T; SOIC127P610X323-8N
IC4: THVD1420DR; SOIC127P600X175-8N
J1: Conn_01x06_MountingPin; PinHeader_1x06_P2.54mm_Vertical
J2: 1984963
J3: 0826-1X1T-GH-F; 08261X1TGHF
J5: 1985069
J6: 1985001
K1, K2: G5Q-1-DC12; G5Q1DC12
L1: DO3316P-333MLD; DO3316P333MLD
L2: FB0805/600R/2A; R_0805_2012Metric
LED1, LED2: LED/GREEN/0603; LED_0201_0603Metric
MH1, MH2, MH3, MH4: Mounting_hole_Shield_3.3mm; MountingHole_3.2mm_M3_Pad
Q1, Q2, Q3, Q4, Q5: BC817-40(SOT23); SOT-23
R1, R5, R7, R21, R26, R27, R33, R34, R35, R36, R37: 1k/R0603; R_0603_1608Metric
R2, R6, R14, R16: 1.2kR/5%/1W/2512/CR2512-JW-122ELF; R_2512_6332Metric
R3, R13, R15, R17: 2.2k/R0402; R_0402_1005Metric
R4, R19, R22, R23, R24, R30: 10k/R0402; R_0402_1005Metric
R8, R9, R10, R12: 49.9R/1%/R0402; R_0402_1005Metric
R18, R32: 470R/R0603; R_0603_1608Metric
R20: 12.1k/1%/R0603; R_0603_1608Metric
R25: 220R/R0402; R_0402_1005Metric
R28, R31: 10R/5%/pulse resistor/0603; R_0603_1608Metric
R29: 130k/R0402; R_0402_1005Metric
R43: 24.9k/1%/R0402; R_0402_1005Metric
R47: 180k/1%/R0402; R_0402_1005Metric
R48: 4.42k/1%/1/16W/R0402; R_0402_1005Metric
R49: 4.7k/R2512; R_2512_6332Metric
R53: 0.03R/1%/R1206; R_1206_3216Metric
R55: 4.7R/R0402; R_0402_1005Metric
R59: 21k/1%/R0402; R_0402_1005Metric
R60: 300k/1%/R0402; R_0402_1005Metric
RN1, RN2: 2.2k/5%/0603x4; R_Array_Concave_4x0603
RST1: T1107A(6x3,8x2,5MM); SW_PUSH_6mm
T1: LMUN2211LT1G(SOT-23); SOT-23
TVS2: ESDS314DBVR(SOT-23-5); SOT-23-5
U1: LAN8710A-EZC(QFN32); QFN50P500X500X100-33N-D
U3: ESP-WROOM-32; ESP32WROOM32EN4
U6: TPS2376DDAR-H (SO-8); SOIC127P600X175-8N
U7: TX4138(ESOIC-8); SOIC8E

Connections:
+3.3V: C1.1, C8.1, C12.2, C13.2, FET1.2, IC1.2 (OUTPUT), IC1.4 (VOUT), IC4.8 (VCC), J1.3, R4.1, R22.1, R24.1, R34.2, R35.2, R36.2, R37.2, U3.2 (3V3)
+3V3: C2.1, C6.1, FET1.3, L2.1, R19.2, RN1.5 (R4_2), RN1.6 (R3_2), RN1.7 (R2_2), RN1.8 (R1_2), RN2.8 (R1_2), U1.12 (VDDIO)
+12V: C5.1, C38.1, C39.1, D1.1 (K), D3.1 (K), IC1.3 (INPUT), J2.1, K1.1 (COIL_1), K2.1 (COIL_1), L1.2, R3.2, R17.2, R60.1
/+Input1: J5.8, R16.1
/+Input2: J5.6, R14.1
/+Input3: J5.4, R6.1
/+Input4: J5.2, R2.1
/-Input1: D8.2 (A), IC2.4 (C_2), J5.7
/-Input2: D7.2 (A), IC2.2 (C_1), J5.5
/-Input3: D11.2 (A), IC3.4 (C_2), J5.3
/-Input4: D10.2 (A), IC3.2 (C_1), J5.1
/D_Com: D5.3, R25.1
/ESP_EN: C31.2, D9.2 (A), R24.2, RST1.1, U3.3 (EN)
/GPI34/Input1: IC2.6 (C_3), R35.1, U3.6 (GPI34/ADC1_CH6/RTC_GPIO4)
/GPI35/Input2: IC2.8 (C_4), R34.1, U3.7 (GPI35/ADC1_CH7/RTC_GPIO5)
/GPI36/Input3: IC3.6 (C_3), R37.1, U3.4 (GPI36/SENSOR_VP/ADC_H/ADC1_CH0/RTC_GPIO0)
/GPI39/Input4: IC3.8 (C_4), R36.1, U3.5 (GPI39/SENSOR_VN/ADC1_CH3/ADC_H/RTC_GPIO3)
/GPIO0: D5.2, U3.25 (GPIO0/ADC2_CH1/TOUCH1/RTC_GPIO11/CLK_OU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)
/GPIO1/UART_TX0: J1.5, U3.35 (GPIO1/U0TXD/CLK_OUT3/EMAC_RXD2)
/GPIO2: D5.1, U3.24 (GPIO2/ADC2_CH2/TOUCH2/RTC_GPIO12/HSPIWP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)
/GPIO3/UART_RX0: J1.4, U3.34 (GPIO3/U0RXD/CLK_OUT2)
/GPIO12/PHY_PWR: T1.1 (B), U3.14 (GPIO12/ADC2_CH5/TOUCH5/RTC_GPIO15/MTDI/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)
/GPIO13/Wiegand_D0/RS485_RX: IC4.1 (R), R18.2, R21.2, R22.2, U3.16 (GPIO13/ADC2_CH4/TOUCH4/RTC_GPIO14/MTCK/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)
/GPIO14/Wiegand_D1/RS485_TX: IC4.4 (D), R32.2, R33.2, U3.13 (GPIO14/ADC2_CH6/TOUCH6/RTC_GPIO16/MTMS/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)
/GPIO15/Wiegand_LED/RS485_DIR: IC4.2 (~RE), IC4.3 (DE), Q5.1 (B), R23.1, U3.23 (GPIO15/ADC2_CH3/TOUCH3/MTDO/HSPICS0/RTC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)
/GPIO17/EMAC_CLK_OUT_180: U1.5 (XTAL1/CLKIN), U3.28 (GPIO17/HS1_DATA5/U2TXD/EMAC_CLK_OUT_180)
/GPIO18/MDIO(RMII): RN1.3 (R3_1), U1.16 (MDIO), U3.30 (GPIO18/VSPICLK/HS1_DATA7)
/GPIO19/EMAC_TXD0(RMII): U1.22 (TXD0), U3.31 (GPIO19/VSPIQ/U0CTS/EMAC_TXD0)
/GPIO21/EMAC_TX_EN(RMII): U1.21 (TXEN), U3.33 (GPIO21/VSPIHD/EMAC_TX_EN)
/GPIO22/EMAC_TXD1(RMII): U1.23 (TXD1), U3.36 (GPIO22/VSPIWP/U0RTS/EMAC_TXD1)
/GPIO23/MDC(RMII): U1.17 (MDC), U3.37 (GPIO23/VSPID/HS1_STROBE)
/GPIO25/EMAC_RXD0(RMII): RN1.2 (R2_1), U1.11 (RXD0/MODE0), U3.10 (GPIO25/DAC_1/ADC2_CH8/RTC_GPIO6/EMAC_RX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)
/GPIO26/EMAC_RXD1(RMII): RN1.1 (R1_1), U1.10 (RXD1/MODE1), U3.11 (GPIO26/DAC_2/ADC2_CH9/RTC_GPIO7/EMAC_RX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)
/GPIO27/EMAC_RX_CRS_DV: RN1.4 (R4_1), U1.15 (COL/CRS_DV/MODE2), U3.12 (GPIO27/ADC2_CH7/TOUCH7/RTC_GPIO17/EMAC_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)
/GPIO32/REL1: R1.1, U3.8 (GPIO32/XTAL_32K_P/ADC1_CH4/TOUCH9/RTC_G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)
/GPIO33/REL2: R5.1, U3.9 (GPIO33/XTAL_32K_N/ADC1_CH5/TOUCH8/RTC_G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)
/RD+: J3.4 (TRD2+), R9.1, TVS2.1 (I/O1), U1.31 (RXP)
/RD-: J3.5 (TRD2-), R8.1, TVS2.5 (I/O4), U1.30 (RXN)
/Relay_1_COM: J6.4, K1.2 (COM)
/Relay_1_NC: J6.6, K1.4 (NC)
/Relay_1_NO: J6.5, K1.3 (NO)
/Relay_2_COM: J6.1, K2.2 (COM)
/Relay_2_NC: J6.3, K2.4 (NC)
/Relay_2_NO: J6.2, K2.3 (NO)
/TD+: J3.11 (TRD1+), R12.1, TVS2.3 (I/O2), U1.29 (TXP)
/TD-: J3.10 (TRD1-), R10.1, TVS2.4 (I/O3), U1.28 (TXN)
/Wiegand_D0/RS485_A: D6.1 (K), J5.11, R18.1, R28.2
/Wiegand_D1/RS485_B: D6.2 (K), J5.10, R31.2, R32.1
/Wiegand_LED: J5.9, Q5.3 (C)
GND: C2.2, C3.1, C4.2, C5.2, C6.2, C7.2, C8.2, C10.2, C12.1, C13.1, C25.2, C26.2, C27.2, C31.1, C35.2, C39.2, D4.2 (A), D6.3 (A), IC1.1 (ADJ/GND), IC2.5 (E_1), IC2.7 (E_2), IC3.5 (E_1), IC3.7 (E_2), IC4.5 (GND), J1.1, J2.2, J5.12, MH1.1 (GND1), MH2.1 (GND1), MH3.1 (GND1), MH4.1 (GND1), Q1.2 (E), Q2.2 (E), Q5.2 (E), R15.2, R20.2, R21.1, R23.2, R33.1, R49.2, R59.2, RN2.5 (R4_2), RN2.6 (R3_2), RN2.7 (R2_2), RST1.2, T1.2 (E), TVS2.2 (GND), U1.24 (TXD2), U1.25 (TXD3), U1.33 (GND), U3.1 (GND), U3.15 (GND), U3.38 (GND), U3.39 (THERMAL_PAD), U3.40 (40_GND), U3.41 (41_GND), U3.42 (42_GND), U3.43 (43_GND), U3.44 (44_GND), U3.45 (45_GND), U3.46 (46_GND), U3.47 (47_GND), U6.5 (RTN), U7.4 (GND)
unnamed: C1.2, FET1.1, R4.2, R7.2
unnamed: C3.2, J3.MH1, J3.MH2
unnamed: C37.2, R55.2
unnamed: D1.2 (A), K1.5 (COIL_2), LED1.1 (K), Q1.3 (C)
unnamed: D3.2 (A), K2.5 (COIL_2), LED2.1 (K), Q2.3 (C)
unnamed: C37.1, D4.1 (K), L1.1, U7.1 (SW)
unnamed: D7.1 (K), IC2.1 (A_1), R14.2
unnamed: D8.1 (K), IC2.3 (A_2), R16.2
unnamed: D9.1 (K), Q3.3 (C)
unnamed: D10.1 (K), IC3.1 (A_1), R2.2
unnamed: D11.1 (K), IC3.3 (A_2), R6.2
unnamed: IC4.6 (A), R31.1
unnamed: IC4.7 (B), R28.1
unnamed: J1.2, Q3.2 (E), R26.1
unnamed: J1.6, Q4.2 (E), R27.1
unnamed: J3.19 (LED_G+), R13.1
unnamed: J3.20 (LED_G-), U1.2 (LED2/NINTSEL)
unnamed: J3.18 (LED_Y+), U1.3 (LED1/REGOFF)
unnamed: J3.17 (LED_Y-), R15.1
unnamed: C4.1, C7.1, C10.1, C25.1, J3.6 (TRCT2), J3.12 (TRCT1), L2.2, R8.2, R9.2, R10.2, R12.2, R13.2, U1.1 (VDD2A), U1.27 (VDD1A)
unnamed: D15.2, J3.13 (VC1)
unnamed: D15.1, J3.14 (VC2)
unnamed: D14.2, J3.15 (VC3)
unnamed: D14.1, J3.16 (VC4)
unnamed: LED1.2 (A), R17.1
unnamed: LED2.2 (A), R3.1
unnamed: Q1.1 (B), R1.2
unnamed: Q2.1 (B), R5.2
unnamed: Q3.1 (B), R27.2
unnamed: Q4.1 (B), R26.2
unnamed: Q4.3 (C), R25.2
unnamed: R53.1, U7.2 (ILIM), U7.9 (ILIM)
unnamed: RN2.1 (R1_1), U1.9 (RXD2/RMIISEL)
unnamed: RN2.2 (R2_1), U1.8 (RXD3/PHYAD2)
unnamed: RN2.3 (R3_1), U1.7 (RXCLK/PHYAD1)
unnamed: RN2.4 (R4_1), U1.13 (RXER/RXD4/PHYAD0)
unnamed: R7.1, T1.3 (C)
unnamed: R19.1, U1.19 (NRST)
unnamed: R20.1, U1.32 (RBIAS)
unnamed: C26.1, C27.1, U1.6 (VDDCR)
unnamed: R48.2, U6.2 (CLASS)
unnamed: R43.2, U6.3 (DET)
unnamed: R47.2, U6.1 (ILIM)
unnamed: R29.2, R30.1, U6.7 (NC/UVLO)
unnamed: U6.6 (PG), U7.6 (EN)
unnamed: R55.1, U7.8 (BS)
unnamed: C38.2, R59.1, R60.2, U7.5 (FB)
Spare1: C34.1, C35.1, D2.2 (A2), D14.3 (+), D15.3 (+), R29.1, R43.1, R49.1, R53.2, U6.8 (VDD), U7.3 (Vin)
Spare2: C34.2, D2.1 (A1), D14.4 (-), D15.4 (-), R30.2, R47.1, R48.1, U6.4 (VSS)

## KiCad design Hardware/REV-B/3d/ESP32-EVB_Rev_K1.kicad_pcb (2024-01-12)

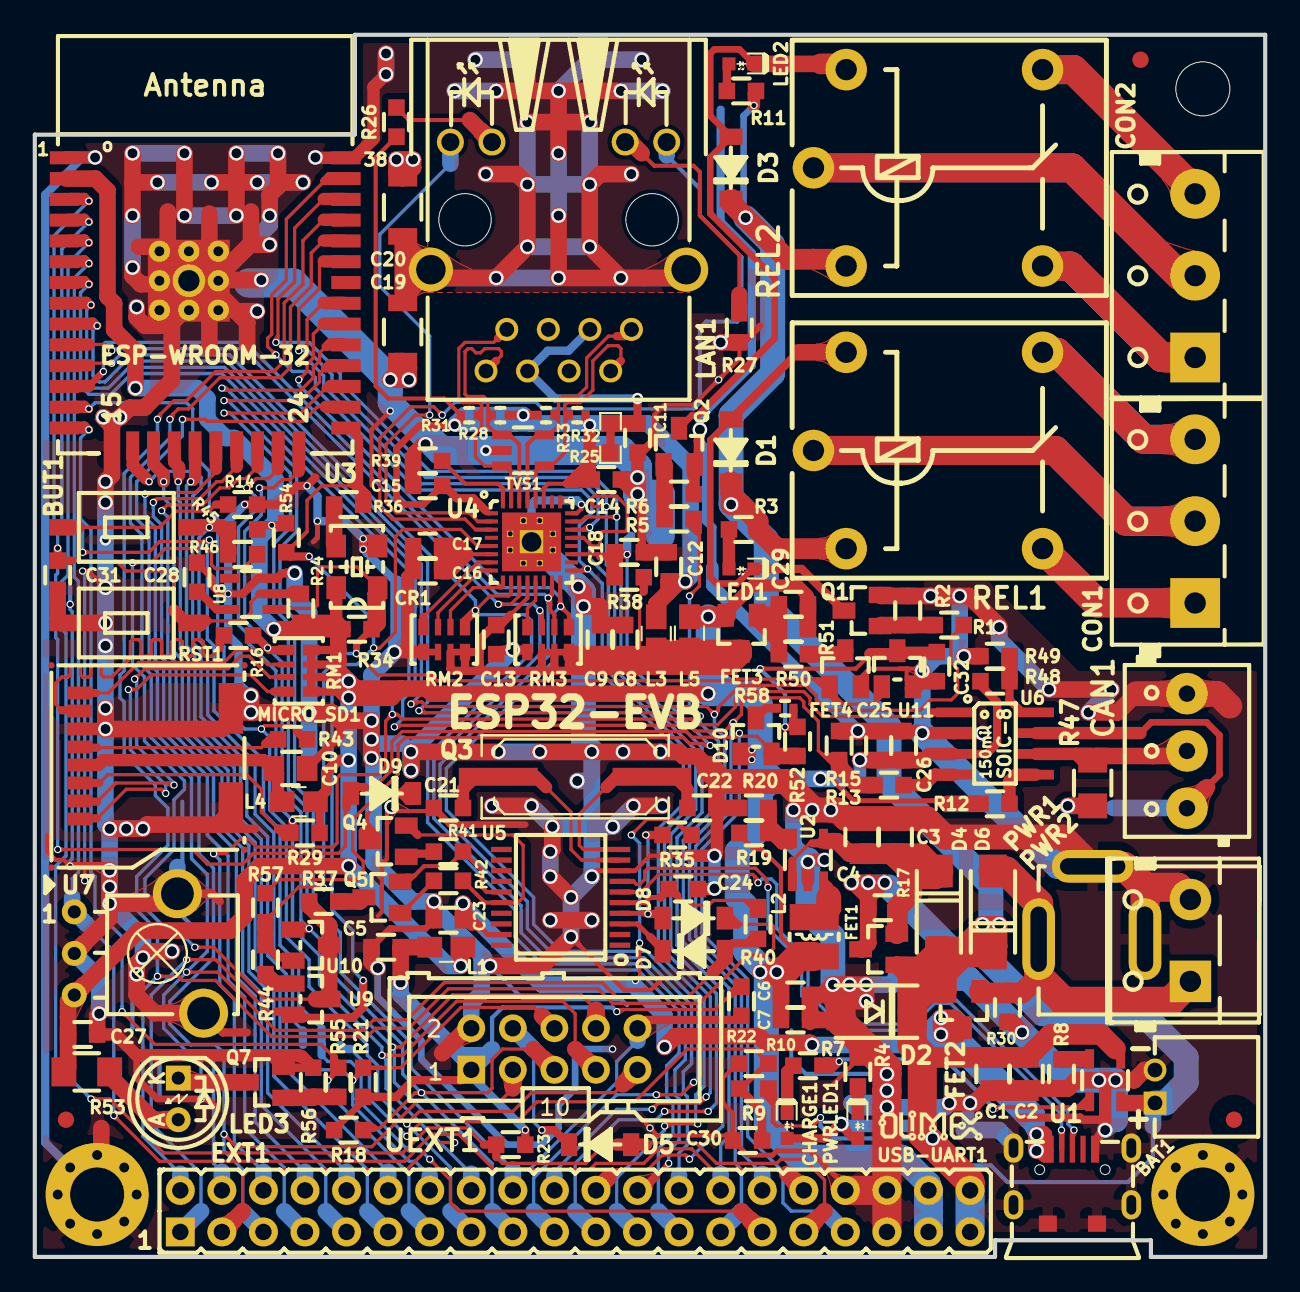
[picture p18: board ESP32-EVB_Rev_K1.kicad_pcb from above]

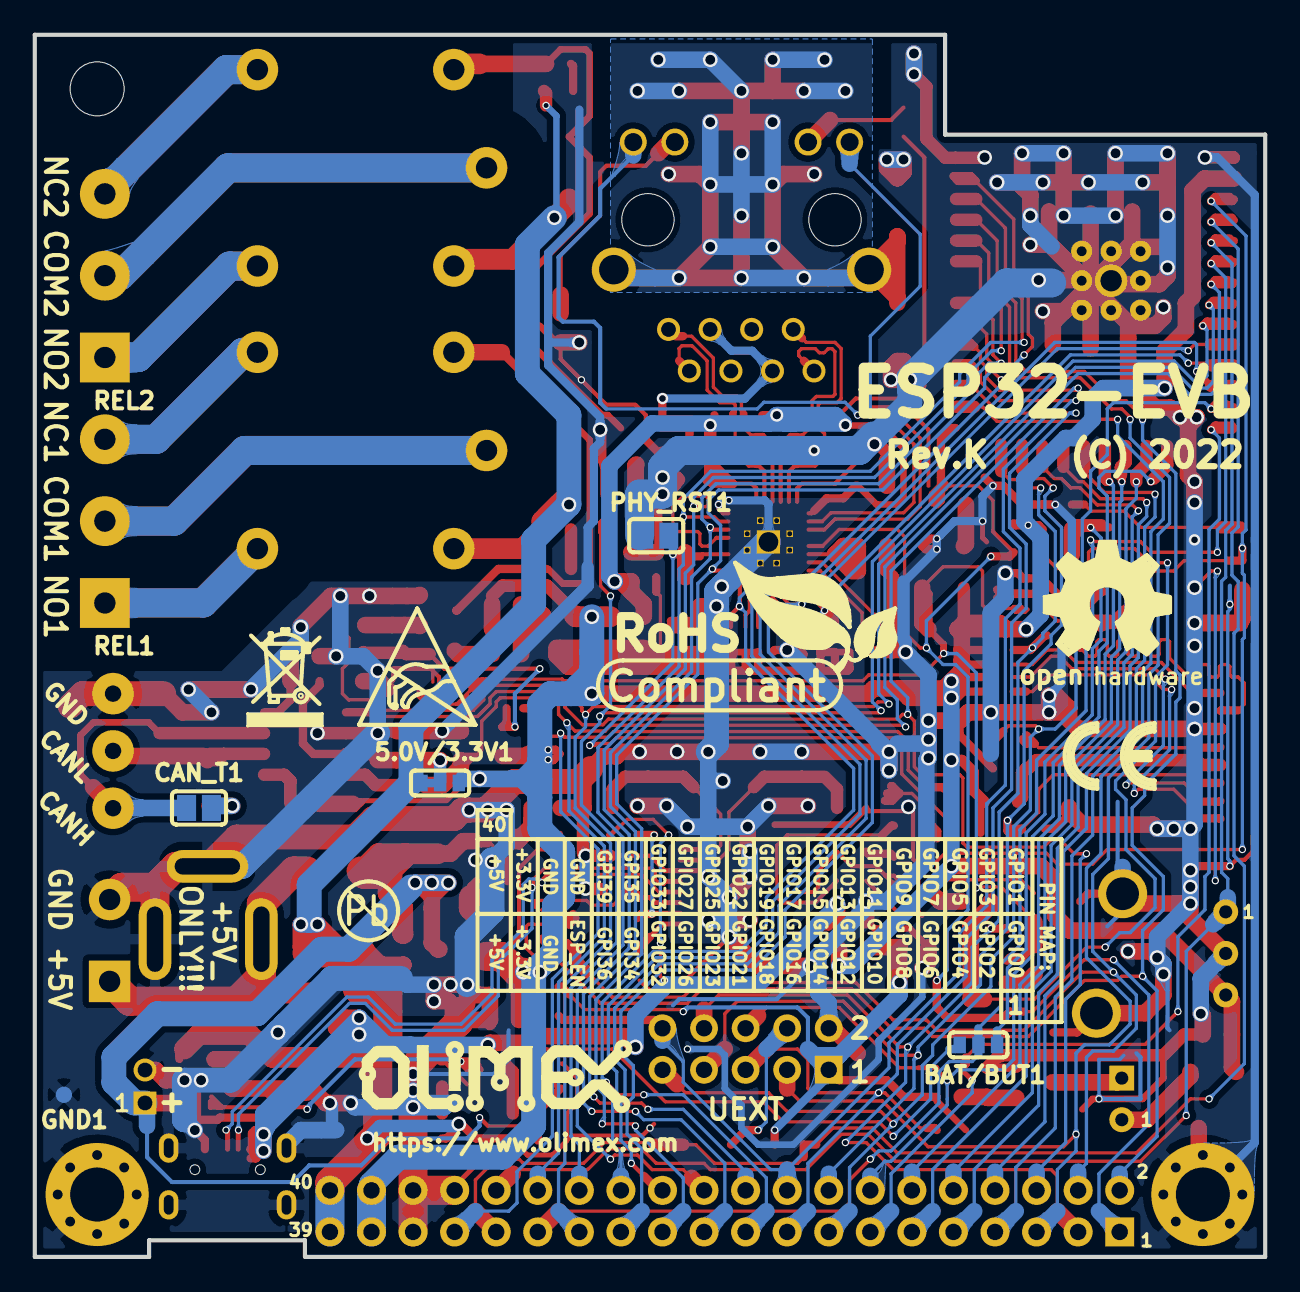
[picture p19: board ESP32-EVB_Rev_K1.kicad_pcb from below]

Board: 2 copper layers, 75.2 x 74.7 mm, 170 parts (12 on the bottom side), 120 nets.

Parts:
5.0V/3.3V1: Closed(1-2)/Opened(2-3); SJ_2_SMALL_12_TIED
BAT1: DW02R; LIPO_BAT-CON2DW02R
BAT/BUT1: Opened(2-3)/Soldered(1-2); SJ_2_SMALL
BUT1: T1107A(6x3,8x2,5MM)
C1, C3: NA(47uF/6.3V/20%/X5R/C0805); C_0805_5MIL_DWS
C2, C4, C10: 47uF/6.3V/20%/X5R/C0805; C_0805_5MIL_DWS
C5, C6, C7, C8, C9, C12, C23, C29: 22uF/6.3V/20%/X5R/C0603; C_0603_5MIL_DWS
C11, C13, C14, C15, C17, C24, C25, C27, C30: 100nF/50V/20%/Y5V/C0603; C_0603_5MIL_DWS
C16: 2.2uF/6.3V/10%/X5R/C0603; C_0603_5MIL_DWS
C18: 1nF/50V/5%/NPO(COG)/C0603; C_0603_5MIL_DWS
C19: 1nF/2000V/10%/X7R/C1206; C_1206_5MIL_DWS_ISO
C20: NA(1nF/2000V/10%/X7R/C1206); C_1206_5MIL_DWS_ISO
C21, C22: 27pF/50V/5%/C0G/C0603; C_0603_5MIL_DWS
C26: 10uF/6.3V/20%/X5R/C0603; C_0603_5MIL_DWS
C28: NA(470nF/16V/10%/X7R/C0603); C_0603_5MIL_DWS
C31, C32: 1uF/10V/10%/X5R/C0603; C_0603_5MIL_DWS
CAN1: TB3-3.5mm
CAN_T1: Opened; SJ
CHARGE1: LED/Yellow/0603; LED_0603_KA
CON1, CON2: TB3-DG306-5.0-3P; TB3-DG306-5.0_3P
CR1: Q50MHz/25ppm/3V/4P/5x3.2mm; 5032-4P_HCX-3S
D1, D3, D5, D7, D8, D9: 1N5819S4(SOD-123); SOD-123_1C-2A_KA
D2: SMBJ6.0A(DO-214AA); DO214AA_1(K)-2(A)
D4, D6: 1N5822/SS34/SMA; SMA-KA
D10: BAT54A(SOT23-3); SOT23-3
EXT1: NA(HN2x20); HN2x20
FET1, FET2, FET3: WPM2015-3/TR; SOT23
FET4: BSS138; SOT23
Fid1, Fid2, Fid3: Fiducial1x3
GND1: TESTPAD; TESTPAD_40-ROUND
L1, L3, L4: FB0805/600R/2A; L_0805_5MIL_DWS
L2: 2.2uH/1.5A/DCR=72mR/20%/3.00x3.00x1.50mm/CD32(NR3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; CD32
L5: NA(FB0805/600R/2A); L_0805_5MIL_DWS
LAN1: RJLD-060TC1(LPJ4013EDNL); RJLBC-060TC1
LED1, LED2: LED/GREEN/0603; LED_0603_KA
LED3: LED/IR333-A/5mm; LED-5mm-PTH-AK
Logo-OSHW: LOGO_OPENHARDWARE_8x8
Logo-Olimex-Big: OLIMEX_LOGO_TB
Logo-Olimex_Small: LOGO_OLIMEX_80
MH1: Mounting_hole_Shield_3.3mm; Mounting_hole_3.3mm
MH2, MH3: Mounting_hole_Shield_3.3mm
MICRO_SD1: TFC-WXCP11-08-LF
PHY_RST1: Opened; SJ
PWR1: PWRJ-2mm(YDJ-1134); PWRJ-2mm(YDJ-1136)
PWR2: NA(TB2 DG306-5.0-2P); TB2-DG306-5.0_2P
PWRLED1: LED/RED/0603; LED_0603_KA
Q1, Q2, Q4, Q5, Q7: BC817-40(SOT23); SOT23
Q3: Q12MHz/20pF/30ppm/2P/HC-49SM(SMD); Q_49U3HMS
R1, R5, R41, R42, R50, R55: 1k/R0603; R_0603_5MIL_DWS
R2, R6, R22, R23, R24, R29, R30, R34, R35, R38, R40, R45, R49, R51, R56: 10k/R0603; R_0603_5MIL_DWS
R3, R4, R7, R11, R18, R21: 2.2k/R0603; R_0603_5MIL_DWS
R8: 2k/1%/R0603; R_0603_5MIL_DWS
R9, R10: 470k/R0603; R_0603_5MIL_DWS
R12, R17, R44, R46, R48, R54: NA/R0603; R_0603_5MIL_DWS
R13: 330R/R0603; R_0603_5MIL_DWS
R14, R16, R26, R27, R37: 220R/R0603; R_0603_5MIL_DWS
R15: 680R/R0603; R_0603_5MIL_DWS
R19: 220k/R0603; R_0603_5MIL_DWS
R20: 49.9k/1%/R0603; R_0603_5MIL_DWS
R25: 0R(board_mounted); 0R_0603
R28, R31, R32, R33, R58: 49.9R/1%/R0402; R_0402_5MIL_DWS
R36, R43: 10R/R0603; R_0603_5MIL_DWS
R39: 12.1k/1%/R0603; R_0603_5MIL_DWS
R47: 120R/R1206; R_1206_5MIL_DWS
R52: 100k/R0603; R_0603_5MIL_DWS
R53: 6.8R/R1206; R_1206_5MIL_DWS
R57: NA(1k/R0603); R_0603_5MIL_DWS
REL1, REL2: RAS-0515; Relay_RAS-05-15
RM1, RM2, RM3: RA1206_(4X0603)_4B8_2.2k; R_MATRIX_4
RST1: T1107A(6x3,8x2,5MM)
Sign-Antistatic: Val**; LOGO_ANTISTATIC_1
Sign-PbFree: LOGO_PBFREE
Sign-RecycleBin: LOGO_RECYCLEBIN_1
Sign-RoHS: Val**; LOGO_ROHS_1
Sign_CE: CE_Sign
TVS1: ESDS314DBVR(SOT-23-5); SOT-23-5
U1: BL4054B-42TPRN(SOT23-5); SOT-23-5
U2: SY8089AAAC(SOT23-5); SOT-23-5
U3: ESP-WROOM-32; ESP-WROOM-32_MODULE
U4: LAN8710A-EZC(QFN32); QFN32_EP(33)_5.00x5.00x0.90mm_Pitch_0.50mm
U5: CH340T(SSOP20W); SSOP-20W
U6: SIT1050T(SOIC-8_150mil); SOIC-8_150mil
U7: VS1838B; RPM7236-H8
U8: NA(NCP303LSN27T1G(SOT-23-5)); SOT-23-5
U9, U10: BAT54C(SOT23-3); SOT23-3
U11: HX7027(SOT-23); SOT-23
UEXT1: BH10S; UEXT_ML10
USB-UART1: MISB-SWMM-5B-LF(USB_MICRO); USB-MICRO_MISB-SWMM-5B_LF

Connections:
+3.3V: 5.0V/3.3V1.3, C6.1, C7.1, C27.1, C29.1, CR1.4, D10.1, EXT1.37, EXT1.38, FET3.2, L1.1, L2.2, L4.1, L5.1, R12.1, R19.2, R24.1, R29.1, R34.1, R45.1, R51.1, R53.1, R54.2, RM1.1.2, RM1.2.2, RM1.3.2, RM1.4.2, U3.2, U7.3
+3.3VLAN: C8.1, C9.1, C13.1, FET3.3, L3.1, L5.2, R38.2, RM2.3.1, RM2.4.1, RM3.1.2, RM3.2.2, RM3.3.2, U4.12
+5V: 5.0V/3.3V1.1, C1.1, C2.1, CHARGE1.2, D1.1, D2.1, D3.1, D4.2, D6.1, EXT1.39, EXT1.40, FET1.1, FET2.2, PWRLED1.2, R3.1, R11.1, REL1.1, REL2.1, U1.4
/+5V_EXT: D6.2, FET2.1, PWR1.+, PWR2.1, R30.1
/+5V_USB: C23.1, FET2.3, R35.1, U5.19, USB-UART1.1
/BUT1: BAT/BUT1.1, BUT1.1, R45.2, R46.1
/CANH: CAN1.3, CAN_T1.2, U6.7
/CANL: CAN1.2, R47.2, U6.6
/D_Com: R37.2, R46.2, U9.3, U10.3
/ESP_EN: C31.2, D9.2, D10.2, EXT1.33, R24.2, R52.2, RST1.1, U3.3, U8.2
/GPI34/BUT1: BAT/BUT1.2, EXT1.29, U3.6
/GPI35/CAN-RX: EXT1.30, R13.1, R15.1, U3.7
/GPI36/U1RXD: D5.2, EXT1.31, R23.2, U3.4
/GPI39/IR_RECEIVE: EXT1.32, U3.5, U7.1
/GPIO0/XTAL1/CLKIN: EXT1.1, R36.2, R54.1, U3.25, U4.5, U9.2
/GPIO1/U0TXD: D8.1, EXT1.2, U3.35
/GPIO2/HS2_DATA0: EXT1.3, R16.1, RM1.1.1, U3.24, U10.1, UEXT1.8
/GPIO3/U0RXD: D7.2, EXT1.4, R40.2, U3.34
/GPIO4/U1TXD: EXT1.5, U3.26, UEXT1.3
/GPIO5/CAN-TX: EXT1.6, U3.29, U6.1
/GPIO6/SD_CLK: EXT1.7, U3.20
/GPIO7/SD_DATA0: EXT1.8, U3.21
/GPIO8/SD_DATA1: EXT1.9, U3.22
/GPIO9/SD_DATA2: EXT1.10, U3.17
/GPIO10/SD_DATA3: EXT1.11, U3.18
/GPIO11/SD_CMD: EXT1.12, U3.19
/GPIO12/IR_Transmit: EXT1.13, R55.1, U3.14
/GPIO13/I2C-SDA: EXT1.14, R21.2, U3.16, UEXT1.6
/GPIO14/HS2_CLK: EXT1.15, R43.1, U3.13, UEXT1.9
/GPIO15/HS2_CMD: EXT1.16, MICRO_SD1.3, R29.2, U3.23, UEXT1.7
/GPIO16/I2C-SCL: EXT1.17, R18.2, U3.27, UEXT1.5
/GPIO17/SPI_CS: EXT1.18, R22.2, U3.28, UEXT1.10
/GPIO18/MDIO(RMII): EXT1.19, RM3.1.1, U3.30, U4.16
/GPIO19/EMAC_TXD0(RMII): EXT1.20, U3.31, U4.22
/GPIO21/EMAC_TX_EN(RMII): EXT1.21, U3.33, U4.21
/GPIO22/EMAC_TXD1(RMII): EXT1.22, U3.36, U4.23
/GPIO23/MDC(RMII): EXT1.23, U3.37, U4.17
/GPIO25/EMAC_RXD0(RMII): EXT1.24, RM3.3.1, U3.10, U4.11
/GPIO26/EMAC_RXD1(RMII): EXT1.25, RM2.4.2, U3.11, U4.10
/GPIO27/EMAC_RX_CRS_DV: EXT1.26, RM3.2.1, U3.12, U4.15
/GPIO32/REL1: EXT1.27, R1.1, U3.8
/GPIO33/REL2: EXT1.28, R5.1, U3.9
/OSC_DIS: CR1.1, FET4.1, R34.2, R44.1, R57.2, U8.1, U10.2, U11.1
/PHYAD0: RM3.4.1, U4.13
/PHYAD1: RM2.1.2, U4.7
/PHYAD2: RM2.2.2, U4.8
/RMIISEL: RM2.3.2, U4.9
/RXN-: LAN1.8, R28.2, TVS1.1, U4.30
/RXP+: LAN1.7, R31.2, TVS1.3, U4.31
/TXN-: LAN1.2, R32.2, TVS1.4, U4.28
/TXP+: LAN1.1, R33.2, TVS1.5, U4.29
/VDD1A-2A: C12.1, C14.1, C15.1, L3.2, R25.1, R26.1, R28.1, R31.1, R32.1, R33.1, U4.1, U4.27
/VDDCR: C16.1, C17.1, U4.6
GND: BAT1.2, C1.2, C2.2, C3.2, C4.2, C5.1, C6.2, C7.2, C8.2, C9.2, C10.2, C11.2, C12.2, C13.2, C14.2, C15.2, C16.2, C17.2, C18.1, C19.2, C20.2, C21.2, C22.2, C23.2, C24.2, C25.1, C26.1, C27.2, C28.2, C30.2, C31.1, C32.1, CAN1.1, CR1.2, D2.2, EXT1.34, EXT1.35, EXT1.36, FET4.2, GND1.1, MH2.GND1, MH3.GND1, MICRO_SD1.6, MICRO_SD1.SH1, MICRO_SD1.SH2, PHY_RST1.1, PWR1.-, PWR2.2, Q1.2, Q2.2, Q7.2, R2.1, R4.2, R6.1, R8.1, R10.2, R14.2, R15.2, R20.2, R27.2, R30.2, R39.2, R49.2, R56.1, RM2.1.1, RM2.2.1, RM3.4.2, RST1.2, TVS1.2, U1.2, U2.2, U3.1, U3.15, U3.38, U3.39, U4.24, U4.25, U4.33, U5.8, U6.2, U7.0, U7.2, U8.3, U11.2, UEXT1.2, USB-UART1.0, USB-UART1.5
unnamed: 5.0V/3.3V1.2, C25.2, C26.2, R48.2, U6.3
unnamed: BAT1.1, FET1.3, R9.1, R17.1, U1.3
unnamed: BAT/BUT1.3, C30.1, R9.2, R10.1
unnamed: BUT1.2, R14.1
unnamed: C3.1, C4.1, D4.1, FET1.2, R17.2, U2.1, U2.4
unnamed: C5.2, L1.2, R18.1, R21.1, R22.1, R23.1, UEXT1.1
unnamed: C10.1, L4.2, MICRO_SD1.4
unnamed: C11.1, LAN1.3, LAN1.6, R25.2
unnamed: C18.2, PHY_RST1.2, R38.1, R57.1, U4.19
unnamed: C19.1, C20.1, LAN1.GND1, LAN1.GND2
unnamed: C21.1, Q3.1, U5.9
unnamed: C22.1, Q3.2, U5.10
unnamed: C24.1, R40.1, U5.5
unnamed: C28.1, U8.5
unnamed: C29.2, FET3.1, R50.2, R51.2
unnamed: C32.2, R52.1, R58.2, U11.3
unnamed: CAN_T1.1, R47.1
unnamed: CHARGE1.1, R7.2
unnamed: CON1.1, REL1.NO0
unnamed: CON1.2, REL1.COM0
unnamed: CON1.3, REL1.NC0
unnamed: CON2.1, REL2.NO0
unnamed: CON2.2, REL2.COM0
unnamed: CON2.3, REL2.NC0
unnamed: CR1.3, R36.1
unnamed: D1.2, LED1.1, Q1.3, REL1.2
unnamed: D3.2, LED2.1, Q2.3, REL2.2
unnamed: D5.1, UEXT1.4
unnamed: D7.1, U5.3
unnamed: D8.2, R35.2, U5.4
unnamed: D9.1, Q4.3
unnamed: D10.3, R58.1
unnamed: FET4.3, R50.1
unnamed: L2.1, U2.3
unnamed: LAN1.AG1, R26.2
unnamed: LAN1.AY1, U4.3
unnamed: LAN1.KG1, U4.2
unnamed: LAN1.KY1, R27.1
unnamed: LED1.2, R3.2
unnamed: LED2.2, R11.2
unnamed: LED3.1, R53.2
unnamed: LED3.2, Q7.3
unnamed: MICRO_SD1.1, RM1.4.1
unnamed: MICRO_SD1.2, RM1.3.1
unnamed: MICRO_SD1.5, R43.2
unnamed: MICRO_SD1.7, R16.2
unnamed: MICRO_SD1.8, RM1.2.1
unnamed: PWRLED1.1, R4.1
unnamed: Q1.1, R1.2, R2.2
unnamed: Q2.1, R5.2, R6.2
unnamed: Q4.1, R41.2
unnamed: Q4.2, R42.1, U5.16
unnamed: Q5.1, R42.2
unnamed: Q5.2, R41.1, U5.15
unnamed: Q5.3, R37.1
unnamed: Q7.1, R55.2, R56.2
unnamed: R7.1, U1.1
unnamed: R8.2, U1.5
unnamed: R12.2, U6.5
unnamed: R13.2, U6.4
unnamed: R19.1, R20.1, U2.5
unnamed: R39.1, U4.32
unnamed: R44.2, U9.1
unnamed: R48.1, R49.1, U6.8
unnamed: U5.6, USB-UART1.3
unnamed: U5.7, USB-UART1.2

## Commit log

2024-01-12 update BOM
    [BOM.csv, BOM.xlsx, ESP32-POE-Wiegand-Relay-REV-B.csv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]
2024-01-13 Readme update
    [ESP32-POE-Wiegand-Relay-REV-B.kicad_sch]
2024-01-13 Update Bornier
    [ESP32-POE-Wiegand-Relay-REV-B.kicad_sch]
2024-01-18 Changer Ethernet Connector, add Switch Wiegand/RS485
    [ESP32-POE-Wiegand-Relay-REV-B.kicad_sch]

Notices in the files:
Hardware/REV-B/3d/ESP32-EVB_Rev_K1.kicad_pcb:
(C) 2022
